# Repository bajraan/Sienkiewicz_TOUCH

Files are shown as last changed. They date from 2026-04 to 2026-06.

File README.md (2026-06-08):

<p align="center" width="100%">
  
</p>

# Sienkiewicz PCB

Sienkiewicz PCB project realized in KiCAD 9

> 🔗 Project main system repository: https://github.com/bajraan/Sienkiewicz__3ART00__SYSTEM

<h1 align="center">3ART12 TOUCH</h1>

<p align="center" width="100%">
  <a href="https://github.com/nguyen-v/KDT_Hierarchical_KiBot/actions/workflows/ci.yaml">
    
  </a>
</p>

***

<p align="center">
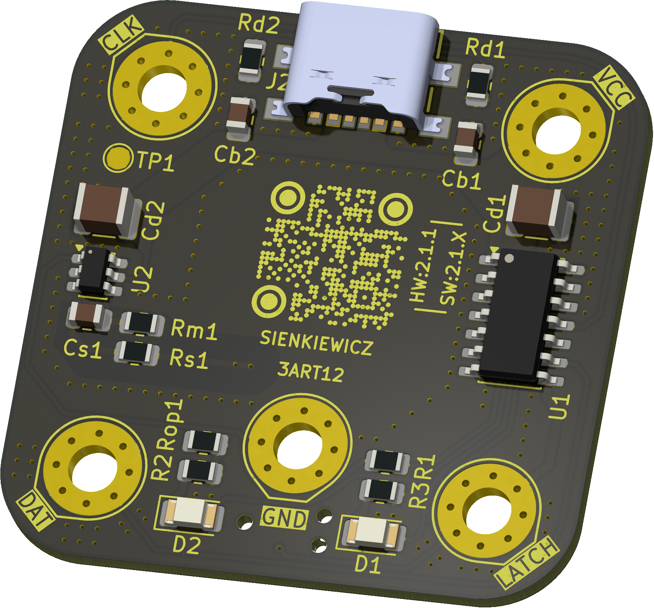
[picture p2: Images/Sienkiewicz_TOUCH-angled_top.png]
3D Top Angled
  
&nbsp; &nbsp; &nbsp; &nbsp;
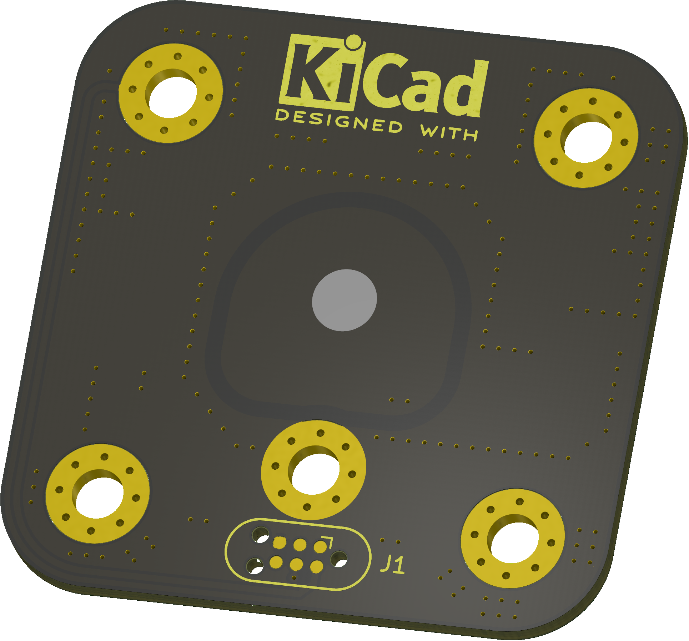
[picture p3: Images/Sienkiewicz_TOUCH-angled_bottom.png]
3D Bottom Angled
  
</p>

***

## SPECIFICATIONS

| Parameter | Value | 
| --- | --- |
| Dimensions | 38.0 × 38.0 mm |

***

## DIRECTORY STRUCTURE

    .
    ├─ Computations       # Misc calculations
    ├─ HTML               # HTML files for generated webpage
    ├─ Images             # Pictures and renders
    │
    ├─ kibot_resources    # External resources for KiBot
    │  ├─ colors          # Color theme for KiCad
    │  ├─ fonts           # Fonts used in the project
    │  ├─ scripts         # External scripts used with KiBot
    │  └─ templates       # Templates for KiBot generated reports
    │
    ├─ kibot_yaml         # KiBot YAML config files
    ├─ KiRI               # KiRI (PCB diff viewer) files
    │
    ├─ lib                # KiCad footprint and symbol libraries
    │  ├─ 3d_models       # Component 3D models
    │  ├─ lib_fp          # Footprint libraries
    │  └─ lib_sym         # Symbol libraries
    │
    ├─ Logos              # Logos
    │
    ├─ Manufacturing      # Assembly and fabrication documents
    │  ├─ Assembly        # Assembly documents (BoM, pos, notes)
    │  │
    │  └─ Fabrication     # Fabrication documents (ZIP, notes)
    │     ├─ Drill Tables # CSV drill tables
    │     └─ Gerbers      # Gerbers
    │
    ├─ Report             # Reports for ERC/DRC
    ├─ Schematic          # PDF of schematic
    ├─ Templates          # Title block templates
    ├─ Testing
    │  └─ Testpoints      # Testpoints tables      
    │
    └─ Variants           # Outputs for assembly variants

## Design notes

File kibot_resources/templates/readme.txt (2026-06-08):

<p align="center" width="100%">
  
</p>

# Sienkiewicz PCB

Sienkiewicz PCB project realized in KiCAD 9

> 🔗 Project main system repository: https://github.com/bajraan/Sienkiewicz__3ART00__SYSTEM

<h1 align="center">${BOARD_NAME}</h1>

<p align="center" width="100%">
  <a href="${GIT_URL}/actions/workflows/ci.yaml">
    CI Badge
  </a>
</p>

***

<p align="center">
  3D Top Angled
&nbsp; &nbsp; &nbsp; &nbsp;
  3D Bottom Angled
</p>

***

## SPECIFICATIONS

| Parameter | Value | 
| --- | --- |
| Dimensions | ${bb_w_mm} × ${bb_h_mm} mm |

***

## DIRECTORY STRUCTURE

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

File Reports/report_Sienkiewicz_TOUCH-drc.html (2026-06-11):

Logo

(https://github.com/INTI-CMNB/KiBot/) | DRC report for Sienkiewicz_TOUCH
| PCB: Sienkiewicz_TOUCH Revision: 2.1.1+ (Unreleased) Date: 2026-06-11T17:48:40+0000 KiCad Version: 9.0.7 | Errors: 0 Warnings: 3 Total: 3

Violations

Type | Description | Details
lib_footprint_mismatch | Footprint 'SOIC-14_3.9x8.7mm_P1.27mm' does not match copy in library 'Package_SO'. | @(161.5 mm, 90.0 mm): Footprint U1
lib_footprint_mismatch | Footprint 'SOT-23-6' does not match copy in library 'Package_TO_SOT_SMD'. | @(133.5 mm, 90.0 mm): Footprint U2

Schematic parity

Type | Description | Details
extra_footprint | Extra footprint | @(148.5 mm, 75.0 mm): Footprint REF**

Generated by KiBot (https://github.com/INTI-CMNB/KiBot/) v1.9.1

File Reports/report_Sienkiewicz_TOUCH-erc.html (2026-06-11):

Logo

(https://github.com/INTI-CMNB/KiBot/) | ERC report for Sienkiewicz_TOUCH
| Schematic: Sienkiewicz_TOUCH Revision: 2.1.1+ (Unreleased) Date: 2026-06-11T17:48:38+0000 KiCad Version: 9.0.7 | Errors: 0 Warnings: 1 Total: 1

Sheet /Project Architecture/Section B - uC/ (Section B - uC.kicad_sch)

Type | Description | Details
pin_to_pin | Pins of type Bidirectional and Power output are connected | @(1.7907 mm, 0.7747 mm): Symbol J1 Pin 2 [SWDIO, Bidirectional, Line] @(1.2954 mm, 0.762 mm): Symbol #FLG01 Pin 1 [Power output, Line]

Generated by KiBot (https://github.com/INTI-CMNB/KiBot/) v1.9.1

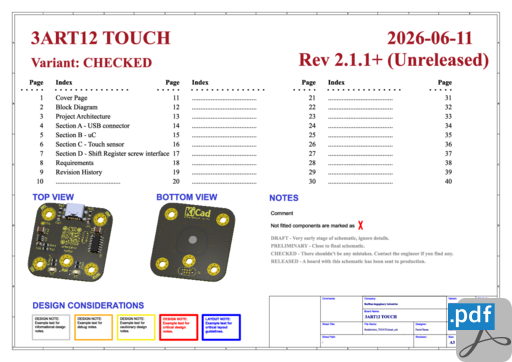
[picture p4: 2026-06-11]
HTML/images/cat_pdf_schematic_Sienkiewicz_TOUCH-schematic.png

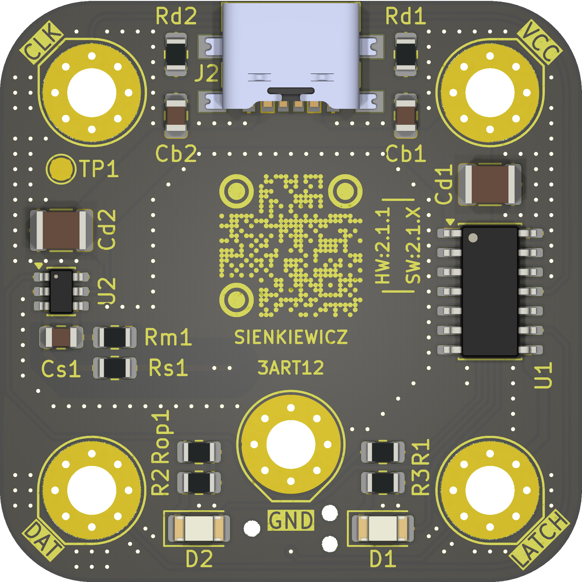
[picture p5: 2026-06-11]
Images/Sienkiewicz_TOUCH-top.png

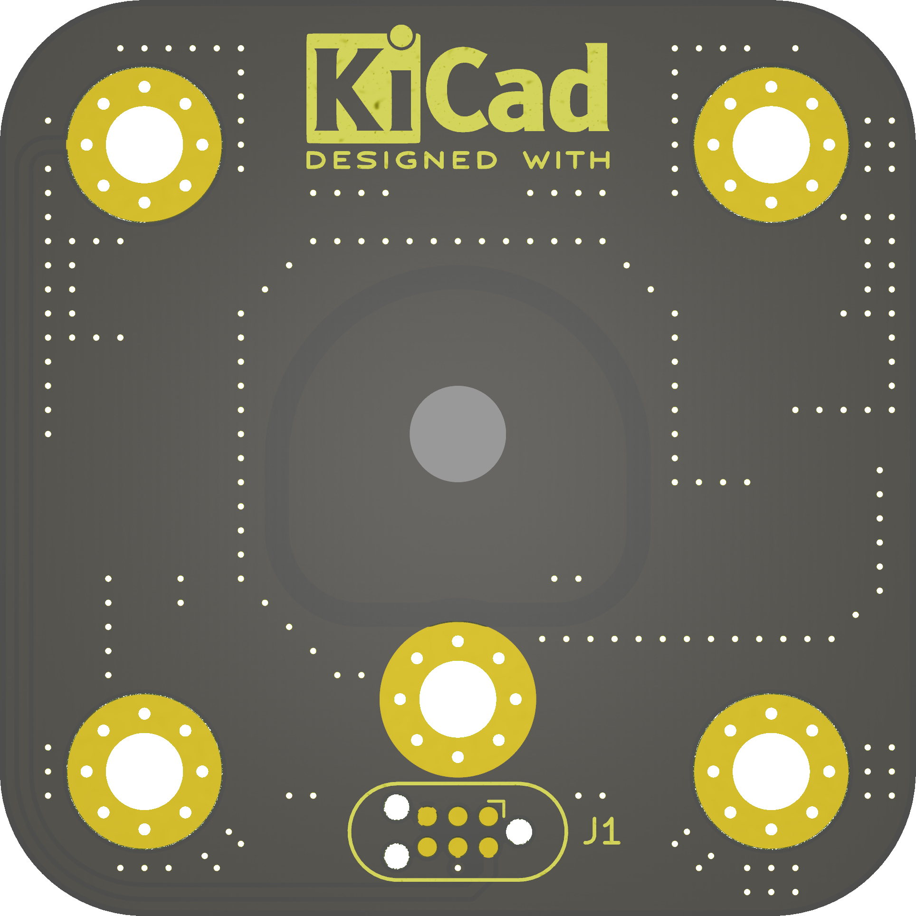
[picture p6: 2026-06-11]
Images/Sienkiewicz_TOUCH-bottom.png

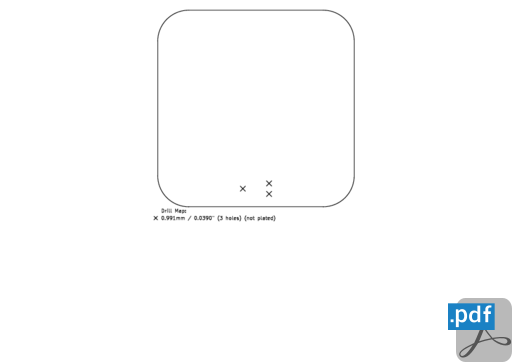
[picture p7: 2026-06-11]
HTML/images/cat_pdf_drill_map_Sienkiewicz_TOUCH-NPTH_drill_map.png

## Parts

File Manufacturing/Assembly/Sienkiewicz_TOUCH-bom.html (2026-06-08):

 | Bill of Materials
 | Schematic: Sienkiewicz_TOUCH Variant: CHECKED Revision: 2.1.1+ (Unreleased) Date: 2025-01-12 KiCad Version: 9.0.7+1 | Component Groups: 13 Component Count: 20 (per PCB) Fitted Components: 20 (per PCB) Number of PCBs: 1 Total Components: 20 (for 1 PCBs)
Row | Quantity Per PCB | References | Value | Datasheet | Footprint | Description | Manufacturer | Manufacturer Part Number | Supplier Part Number
1 | 1 | B1 | BOARD_OUTLINE |  | Sienkiewicz
2 | 2 | Cb1 Cb2 | 1u/16V | ~ | C_0805_2012Metric | Unpolarized capacitor
3 | 2 | Cd1 Cd2 | 100nF | ~ | C_1210_3225Metric | Unpolarized capacitor, small symbol
4 | 1 | Cs1 | 2n7 | ~ | C_0805_2012Metric | Unpolarized capacitor, small symbol
5 | 2 | D1 D2 | RED | ~ | LED_1206_3216Metric | Diode, small symbol
6 | 1 | J2 | USB4135-GF-A_REVA |  | GCT_USB4135-GF-A_REVA |  | GCT
7 | 3 | R1 R2 R3 | 1k | ~ | R_0805_2012Metric | Resistor, small symbol
8 | 3 | Rd1 Rd2 Rs1 | 5k1 | ~ | R_0805_2012Metric | Resistor, small symbol
9 | 1 | Rm1 | 1M | ~ | R_0805_2012Metric | Resistor, small symbol
10 | 1 | Rop1 | 100k | ~ | R_0805_2012Metric | Resistor, small symbol
11 | 1 | TouP1 | TouchPad | ~ | TouchPAD | touch pad
12 | 1 | U2 | AT42QT1012-T | http://ww1.microchip.com/downloads/en/DeviceDoc/40001948A.pdf | SOT-23-6 | Single-Key Touch Sensor IC, SOT-23-6
13 | 1 | U1 | ATtiny204-SS | http://ww1.microchip.com/downloads/en/DeviceDoc/50002687A.pdf | SOIC-14_3.9x8.7mm_P1.27mm | 20MHz, 2kB Flash, 128B SRAM, 64B EEPROM, SOIC-14
Color reference for columns:
KiCad Fields (default)
Generated Fields
User Fields
Empty Fields

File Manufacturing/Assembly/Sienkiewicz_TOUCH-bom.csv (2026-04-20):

Row | Quantity Per PCB | References | Value | Datasheet | Footprint | Description | Manufacturer | Manufacturer Part Number | Supplier Part Number | BOM_STATUS | BOM_INFO
1 | 1 | B1 | BOARD_OUTLINE |  | Sienkiewicz |  |  |  |  | N/A | N/A
2 | 2 | Cb1 Cb2 | 1u/16V | ~ | C_0805_2012Metric | Unpolarized capacitor |  |  |  | OK | TME BOX
3 | 2 | Cd1 Cd2 | 100nF | ~ | C_1210_3225Metric | Unpolarized capacitor, small symbol |  |  |  | OK | AIDATEK A0
4 | 1 | Cs1 | 2n7 | ~ | C_0805_2012Metric | Unpolarized capacitor, small symbol |  |  |  | OK | TME BOX
5 | 2 | D1 D2 | RED | ~ | LED_1206_3216Metric | Diode, small symbol |  |  |  | OK | AIDATEK A0
6 | 1 | J2 | USB4135-GF-A_REVA |  | GCT_USB4135-GF-A_REVA |  | GCT |  |  | OK | TME BOX
7 | 3 | R1 R2 R3 | 1k | ~ | R_0805_2012Metric | Resistor, small symbol |  |  |  | OK | AIDATEK A0
8 | 3 | Rd1 Rd2 Rs1 | 5k1 | ~ | R_0805_2012Metric | Resistor, small symbol |  |  |  | OK | TME BOX 25.06.2025
9 | 1 | Rm1 | 1M | ~ | R_0805_2012Metric | Resistor, small symbol |  |  |  | OK | TME BOX
10 | 1 | Rop1 | 100k | ~ | R_0805_2012Metric | Resistor, small symbol |  |  |  | OK | TME BOX
11 | 1 | TouP1 | TouchPad | ~ | TouchPAD | touch pad |  |  |  | N/A | N/A
12 | 1 | U2 | AT42QT1012-T | http://ww1.microchip.com/downloads/en/DeviceDoc/40001948A.pdf | SOT-23-6 | Single-Key Touch Sensor IC, SOT-23-6 |  |  |  | OK | TME BOX
13 | 1 | U1 | ATtiny204-SS | http://ww1.microchip.com/downloads/en/DeviceDoc/50002687A.pdf | SOIC-14_3.9x8.7mm_P1.27mm | 20MHz, 2kB Flash, 128B SRAM, 64B EEPROM, SOIC-14 |  |  |  | OK | AIDATEK A1

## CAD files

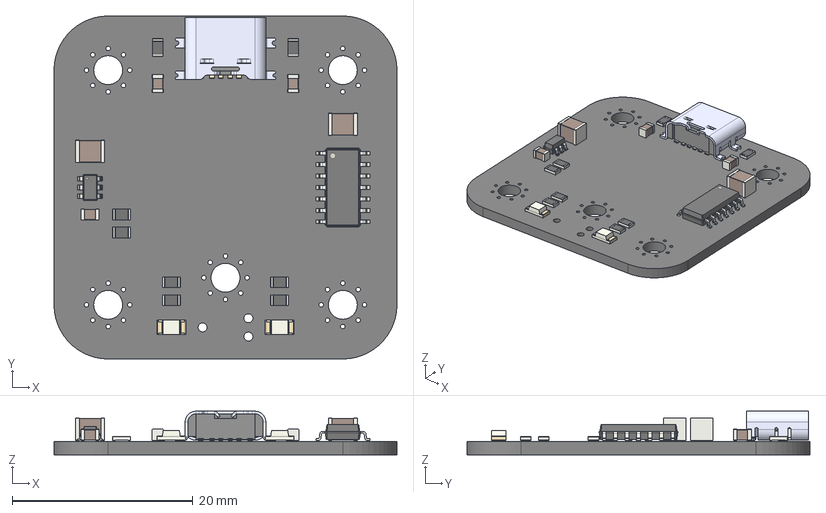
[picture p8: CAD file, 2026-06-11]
3D/Sienkiewicz_TOUCH.step
38.0 x 38.0 x 4.84 mm
R_0805_2012Metric x 8
LED_1206_3216Metric x 2
SOIC-14_3.9x8.7mm_P1.27mm
C_0805_2012Metric x 3
C_1210_3225Metric x 2
USB4135-GF-A_REVA
SOT-23-6
kibot_naao430z_PCB

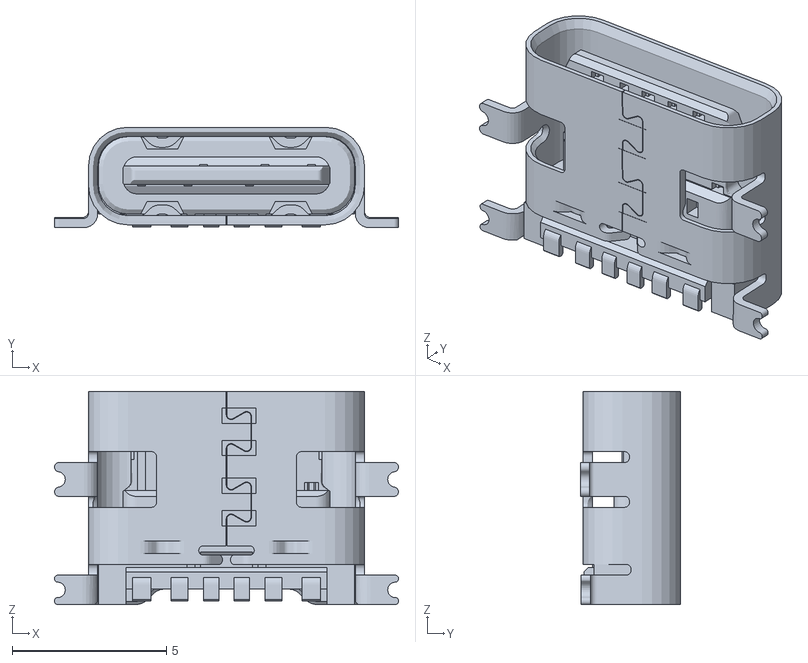
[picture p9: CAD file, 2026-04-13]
__GCT_USB4135-GF-A/usb4135-gf-a.stl
11.1 x 3.25 x 6.90

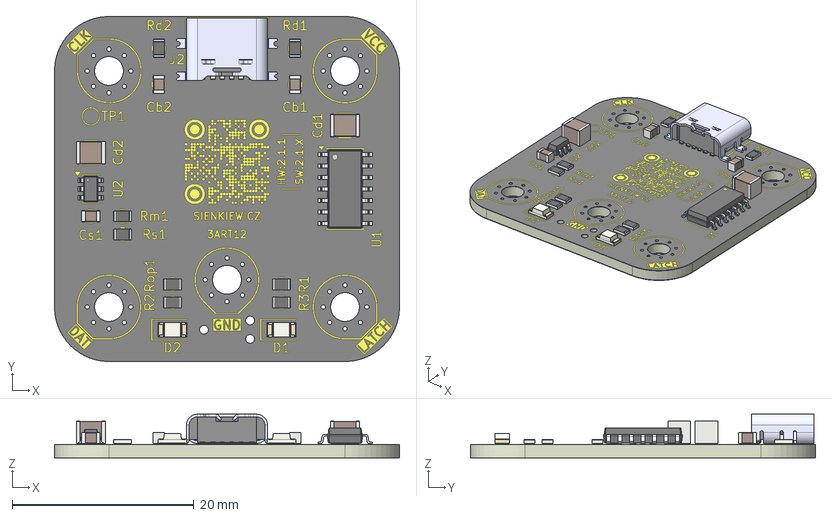
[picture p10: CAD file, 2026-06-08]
STEP_Blender/KDT_Hierarchical_KiBot.step
38.0 x 38.0 x 4.91 mm
R_0805_2012Metric x 8
LED_1206_3216Metric x 2
SOIC-14_3.9x8.7mm_P1.27mm
C_0805_2012Metric x 3
C_1210_3225Metric x 2
USB4135-GF-A_REVA
SOT-23-6
Sienkiewicz_TOUCH_silkscreen x 2
Sienkiewicz_TOUCH_soldermask x 2
Sienkiewicz_TOUCH_PCB

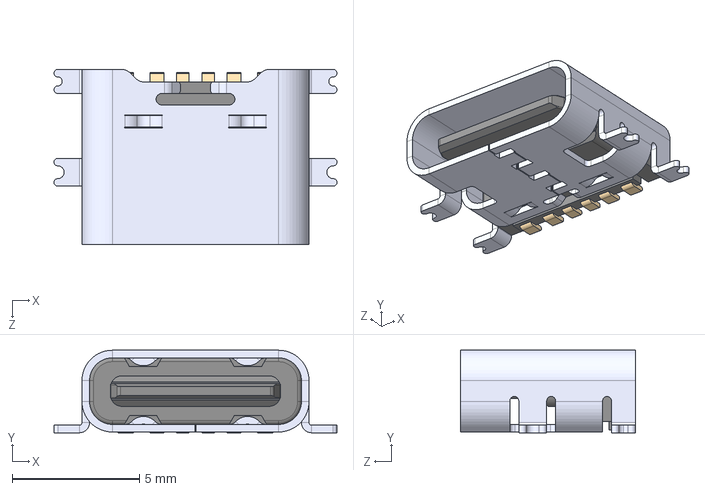
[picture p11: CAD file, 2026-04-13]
__GCT_USB4135-GF-A/USB4135-GF-A_REVA.step
11.1 x 3.25 x 6.90 mm

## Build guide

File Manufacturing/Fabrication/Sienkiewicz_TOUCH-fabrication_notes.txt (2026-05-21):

FABRICATION NOTES (UNLESS OTHERWISE SPECIFIED)

1)	FABRICATE PER IPC-6012A CLASS 2.

2)	OUTLINE DEFINED IN SEPARATE GERBER FILE WITH
	"Edge_Cuts.GBR" SUFFIX.

	DIMENSIONS OF CIRCUMSIZED RECTANGLE SHOWN ON THIS
	DRAWING FOR REFERENCE ONLY.

3)	SEE SEPARATE DRILL FILES WITH ".DRL" SUFFIX 
	FOR HOLE LOCATIONS.

	SELECTED HOLE LOCATIONS SHOWN ON THIS DRAWING 
	FOR REFERENCE ONLY.

4)	SURFACE FINISH: IMMERSION GOLD

5)	SOLDERMASK ON BOTH SIDES OF THE BOARD SHALL 
	BE LPI, COLOR BLACK.

6)	SILK SCREEN LEGEND TO BE APPLIED PER LAYER 
	STACKUP USING YELLOW NON-CONDUCTIVE EPOXY INK.

7)	ALL VIAS ARE TENTED ON BOTH SIDES UNLESS 
	SOLDERMASK OPENED IN GERBER.

8)	VENDOR SHOULD FOLLOW ROHS COMPLIANT PROCESS 
	AND Pb FREE FOR MANUFACTURING

9)	PCB MATERIAL REQUIREMENTS:

	A.	FLAMMABILITY RATING MUST MEET OR EXCEED 
		UL94V-0 REQUIREMENTS.
	B.	Tg 170 C OR EQUIVALENT.
	C.	EQUIVALENT MATERIAL SHALL BE RoHS COMPLIANT, 
		HALOGEN FREE AND APPROVED BY BAJRAN IMGAGINARY INDUSTRIES.

10)	DESIGN GEOMETRY MINIMUM FEATURE SIZES:

	BOARD SIZE				38.000 × 38.000 mm
	BOARD THICKNESS		1.610 mm
	TRACE WIDTH			0.200 mm
	TRACE TO TRACE		-0.000 mm
	MIN. HOLE (PTH)			0.250 mm
	MIN. HOLE (NPTH)		1.000 mm
	ANNULAR RING			0.150 mm
	COPPER TO HOLE		0.254 mm
	COPPER TO EDGE		0.250 mm
	HOLE TO HOLE			0.254 mm

11)	REFER TO IMPEDANCE TABLE FOR IMPEDANCE CONTROL REQUIREMENTS.

12)	CONFIRM SPACE WIDTHS AND SPACINGS.

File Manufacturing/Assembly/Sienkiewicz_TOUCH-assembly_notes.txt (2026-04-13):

ASSEMBLY NOTES (UNLESS OTHERWISE SPECIFIED)

1)	DO NOT POPULATE PARTS ARE MARKED WITH A RED CROSS.

2)	DO NOT POPULATE PARTS ARE NOT PRESENT IN THE BOM.

3)	IF CONFLICTING INFORMATION IS FOUND BETWEEN THE ASSEMBLY
	FILE AND BOM, BOM SHOULD BE USED AS THE MAIN SOURCE.

4)	CONFORMAL COATING IS NOT REQUIRED.

5)	DOT IDENTIFIES PIN #1 LOCATION AND DEVICE ORIENTATION
	WHEN VIEWED FROM THE TOP.

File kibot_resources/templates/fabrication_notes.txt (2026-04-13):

FABRICATION NOTES (UNLESS OTHERWISE SPECIFIED)

1)	FABRICATE PER IPC-6012A CLASS 2.

2)	OUTLINE DEFINED IN SEPARATE GERBER FILE WITH
	"Edge_Cuts.GBR" SUFFIX.

	DIMENSIONS OF CIRCUMSIZED RECTANGLE SHOWN ON THIS
	DRAWING FOR REFERENCE ONLY.

3)	SEE SEPARATE DRILL FILES WITH ".DRL" SUFFIX 
	FOR HOLE LOCATIONS.

	SELECTED HOLE LOCATIONS SHOWN ON THIS DRAWING 
	FOR REFERENCE ONLY.

4)	SURFACE FINISH: ${pcb_finish_cap}

5)	SOLDERMASK ON BOTH SIDES OF THE BOARD SHALL 
	BE LPI, COLOR ${solder_mask_color_text_cap}.

6)	SILK SCREEN LEGEND TO BE APPLIED PER LAYER 
	STACKUP USING ${silk_screen_color_text_cap} NON-CONDUCTIVE EPOXY INK.

7)	ALL VIAS ARE TENTED ON BOTH SIDES UNLESS 
	SOLDERMASK OPENED IN GERBER.

8)	VENDOR SHOULD FOLLOW ROHS COMPLIANT PROCESS 
	AND Pb FREE FOR MANUFACTURING

9)	PCB MATERIAL REQUIREMENTS:

	A.	FLAMMABILITY RATING MUST MEET OR EXCEED 
		UL94V-0 REQUIREMENTS.
	B.	Tg 170 C OR EQUIVALENT.
	C.	EQUIVALENT MATERIAL SHALL BE RoHS COMPLIANT, 
		HALOGEN FREE AND APPROVED BY ${COMPANY_cap}.

10)	DESIGN GEOMETRY MINIMUM FEATURE SIZES:

	BOARD SIZE				${bb_w_mm} × ${bb_h_mm} mm
	BOARD THICKNESS		${thickness_mm} mm
	TRACE WIDTH			${track_mm} mm
	TRACE TO TRACE		${clearance_mm} mm
	MIN. HOLE (PTH)			${drill_pth_real_mm} mm
	MIN. HOLE (NPTH)		${drill_npth_real_mm} mm
	ANNULAR RING			${oar_mm} mm
	COPPER TO HOLE		${c2h_mm} mm
	COPPER TO EDGE		${c2e_mm} mm
	HOLE TO HOLE			${h2h_mm} mm
#?stackup and impedance_controlled

#?stackup and impedance_controlled
11)	REFER TO IMPEDANCE TABLE FOR IMPEDANCE CONTROL REQUIREMENTS.
#?stackup and impedance_controlled

#?stackup and impedance_controlled
12)	CONFIRM SPACE WIDTHS AND SPACINGS.

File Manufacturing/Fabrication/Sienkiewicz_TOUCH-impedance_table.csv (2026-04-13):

Transmission Line | Impedance [ohms] | Tolerance [ohms] | Layer | Trace Width [mm] | Gap [mm] | Ref. Layers
Edge-Coupled Coated Microstrip | 100 | ±10 % | L1 | 0.2032 | 0.28 | L2

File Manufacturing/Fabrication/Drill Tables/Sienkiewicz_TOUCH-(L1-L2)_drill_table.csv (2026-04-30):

Count | Hole Size | Plated | Hole Shape | Drill Layer Pair | Hole Type
183 | 0.25mm (9.84mils) | PTH | Round | F.Cu - B.Cu | Via
40 | 0.50mm (19.69mils) | PTH | Round | F.Cu - B.Cu | Pad
5 | 3.20mm (125.98mils) | PTH | Round | F.Cu - B.Cu | Pad
Total 228

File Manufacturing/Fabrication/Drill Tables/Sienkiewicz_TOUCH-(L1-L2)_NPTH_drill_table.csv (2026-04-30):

Count | Hole Size | Plated | Hole Shape | Drill Layer Pair | Hole Type
3 | 0.99mm (39.00mils) | NPTH | Round | F.Cu - B.Cu | Mechanical
Total 3

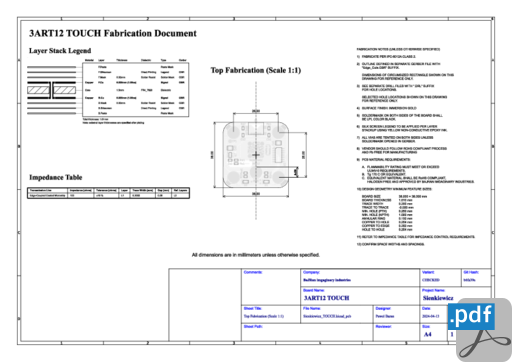
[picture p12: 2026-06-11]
HTML/images/cat_pdf_fabrication_Sienkiewicz_TOUCH-fabrication.png

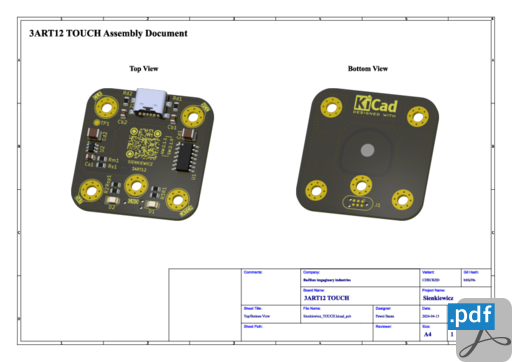
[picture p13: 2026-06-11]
HTML/images/cat_pdf_assembly_Sienkiewicz_TOUCH-assembly.png

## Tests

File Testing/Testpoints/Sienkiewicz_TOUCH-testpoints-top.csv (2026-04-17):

Ref. | Net | X [mm] | Y [mm]
TP1 | GND | 69.50 | 24.00

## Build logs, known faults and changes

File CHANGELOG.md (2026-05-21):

# Changelog

## [Unreleased]

## [2.1.1] - 2026-05-21

### Changed

-   B-B connector maping changes restored (fixes #4)

### Added

-   requirements section added for documentation

## [2.1.0] - 2026-05-01

### Changed

-   B-B connector maping changes, CLK and SDI swapped (fixes #4)

## [2.0.2] - 2026-04-26

### Changed

-   Modified silkscreen look
-   Fabrication layers update

## [2.0.1] - 2026-04-25

### Changed

-   Modified silkscreen look, by adding bigger QR-code. small rearangment.

## [2.0.0] - 2026-04-24

### Added

-   First 2.0.0 Version of pcb and schematic

[Unreleased]: https://github.com/bajraan/Sienkiewicz_TOUCH/compare/2.1.1...HEAD

[2.1.1]: https://github.com/bajraan/Sienkiewicz_TOUCH/compare/2.1.0...2.1.1

[2.1.0]: https://github.com/bajraan/Sienkiewicz_TOUCH/compare/2.0.2...2.1.0

[2.0.2]: https://github.com/bajraan/Sienkiewicz_TOUCH/compare/2.0.1...2.0.2

[2.0.1]: https://github.com/bajraan/Sienkiewicz_TOUCH/compare/2.0.0...2.0.1

[2.0.0]: https://github.com/bajraan/Sienkiewicz_TOUCH/compare/a58dfeffc68793d9061ed17c15873d52f7ee5985...2.0.0

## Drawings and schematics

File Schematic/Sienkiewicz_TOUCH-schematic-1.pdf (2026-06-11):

# Variant:CHECKED

# 3ART12TOUCH

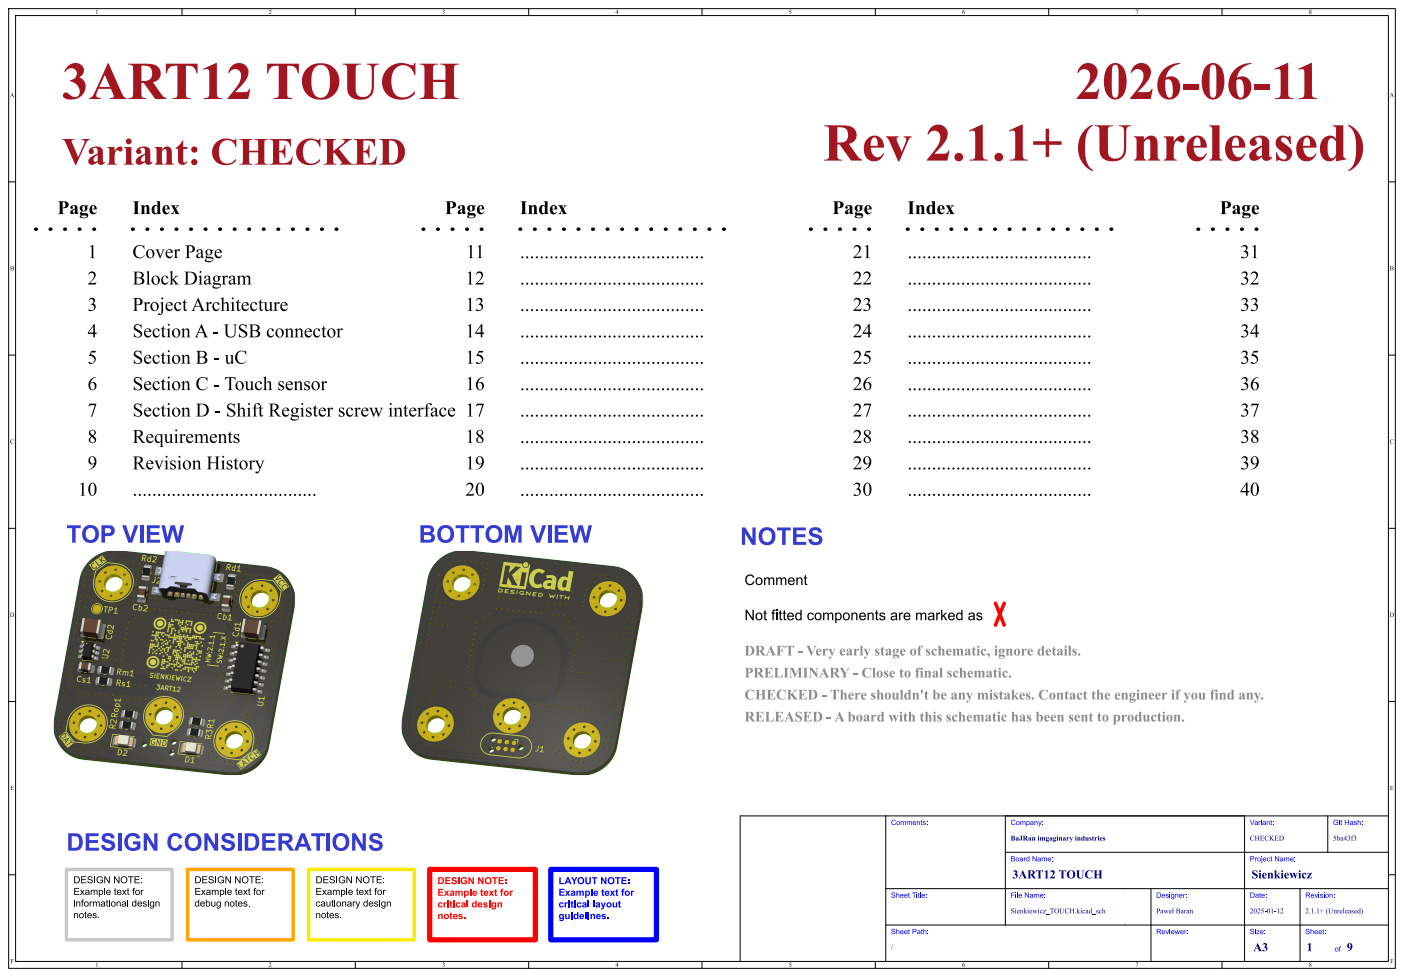
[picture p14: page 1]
Sheet: of 9; Size: A3; Sienkiewicz_TOUCH.kicad_sch; þÿPaweB Baran Board Name:; Variant: CHECKED; Company: BaJRanimgaginaryindustries 3ART12TOUCH; Sienkiewicz; Sheet Title:; File Name:; /Sheet Path: Comments:; Git Hash: 5ba43f3 ProjectArchitecture; kibot_image_png_3d_viewer_angled_bottom; LAYOUT NOTE:; kibot_image_png_3d_viewer_angled_top; DESIGN NOTE:; RELEASED - A boardwiththisschematichasbeensenttoproduction.; RevisionHistory; Index; Page; NOTES; Comment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

CoverPage
Block Diagram
ProjectArchitecture
SectionA - USBconnector
...................................... SectionB - uC
SectionC - Touchsensor
SectionD - Shift Registerscrewinterface
Requirements

Not fitted components are marked as

DRAFT - Veryearlystageof schematic,ignoredetails.
PRELIMINARY - Closetofinal schematic.

Revision: 2.1.1+(Unreleased) Date: Project Name: 2025-01-12 Reviewer: Designer:

DESIGN NOTE:
Example text for
informational design
notes.

debug notes.

critical design

cautionary design

critical layout
guidelines.

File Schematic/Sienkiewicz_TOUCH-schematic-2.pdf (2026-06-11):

## Page5

# STATUS

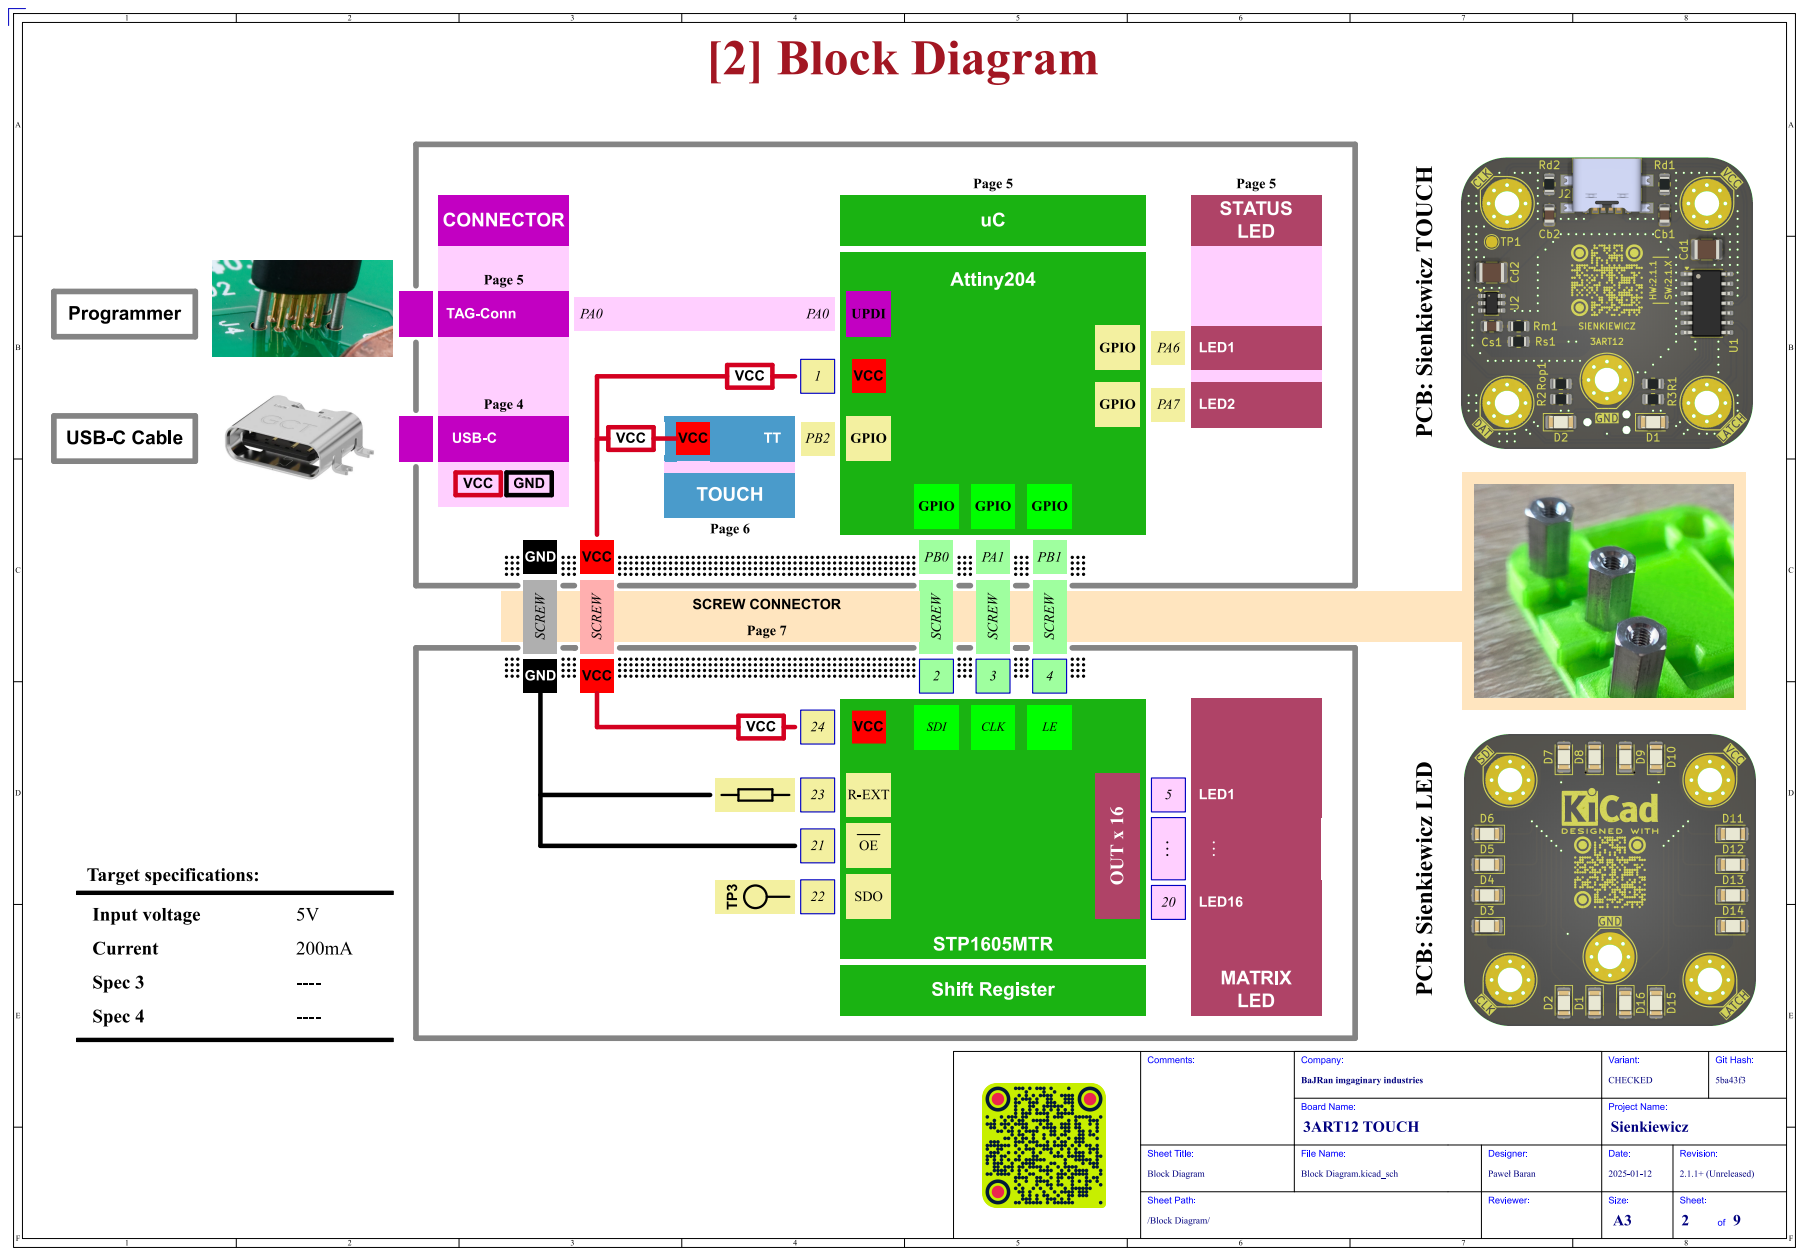
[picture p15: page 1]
Sheet: of 9; Size: A3; Revision: 2.1.1+(Unreleased) Date: Project Name: 2025-01-12 Reviewer: Designer: Block Diagram.kicad_sch; þÿPaweB Baran Board Name:; Variant: CHECKED; Company: BaJRanimgaginaryindustries 3ART12TOUCH; Sienkiewicz; Sheet Title:; File Name:; Comments:; Git Hash: 5ba43f3 5; LED1; VCC; LED; LED2; Page6; GPIO; STP1605MTR; Shift Register; OUT; TOUCH; Spec4; CONNECTOR; USB-C; TAG-Conn; Page5; SCREW; USB-C Cable; Spec3; Current; Input voltage; Targetspecifications:; GND; LED16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

/Block Diagram/ Sheet Path: Block Diagram

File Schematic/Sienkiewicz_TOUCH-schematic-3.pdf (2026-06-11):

## SectionB - uC

# [3] ProjectArchitecture

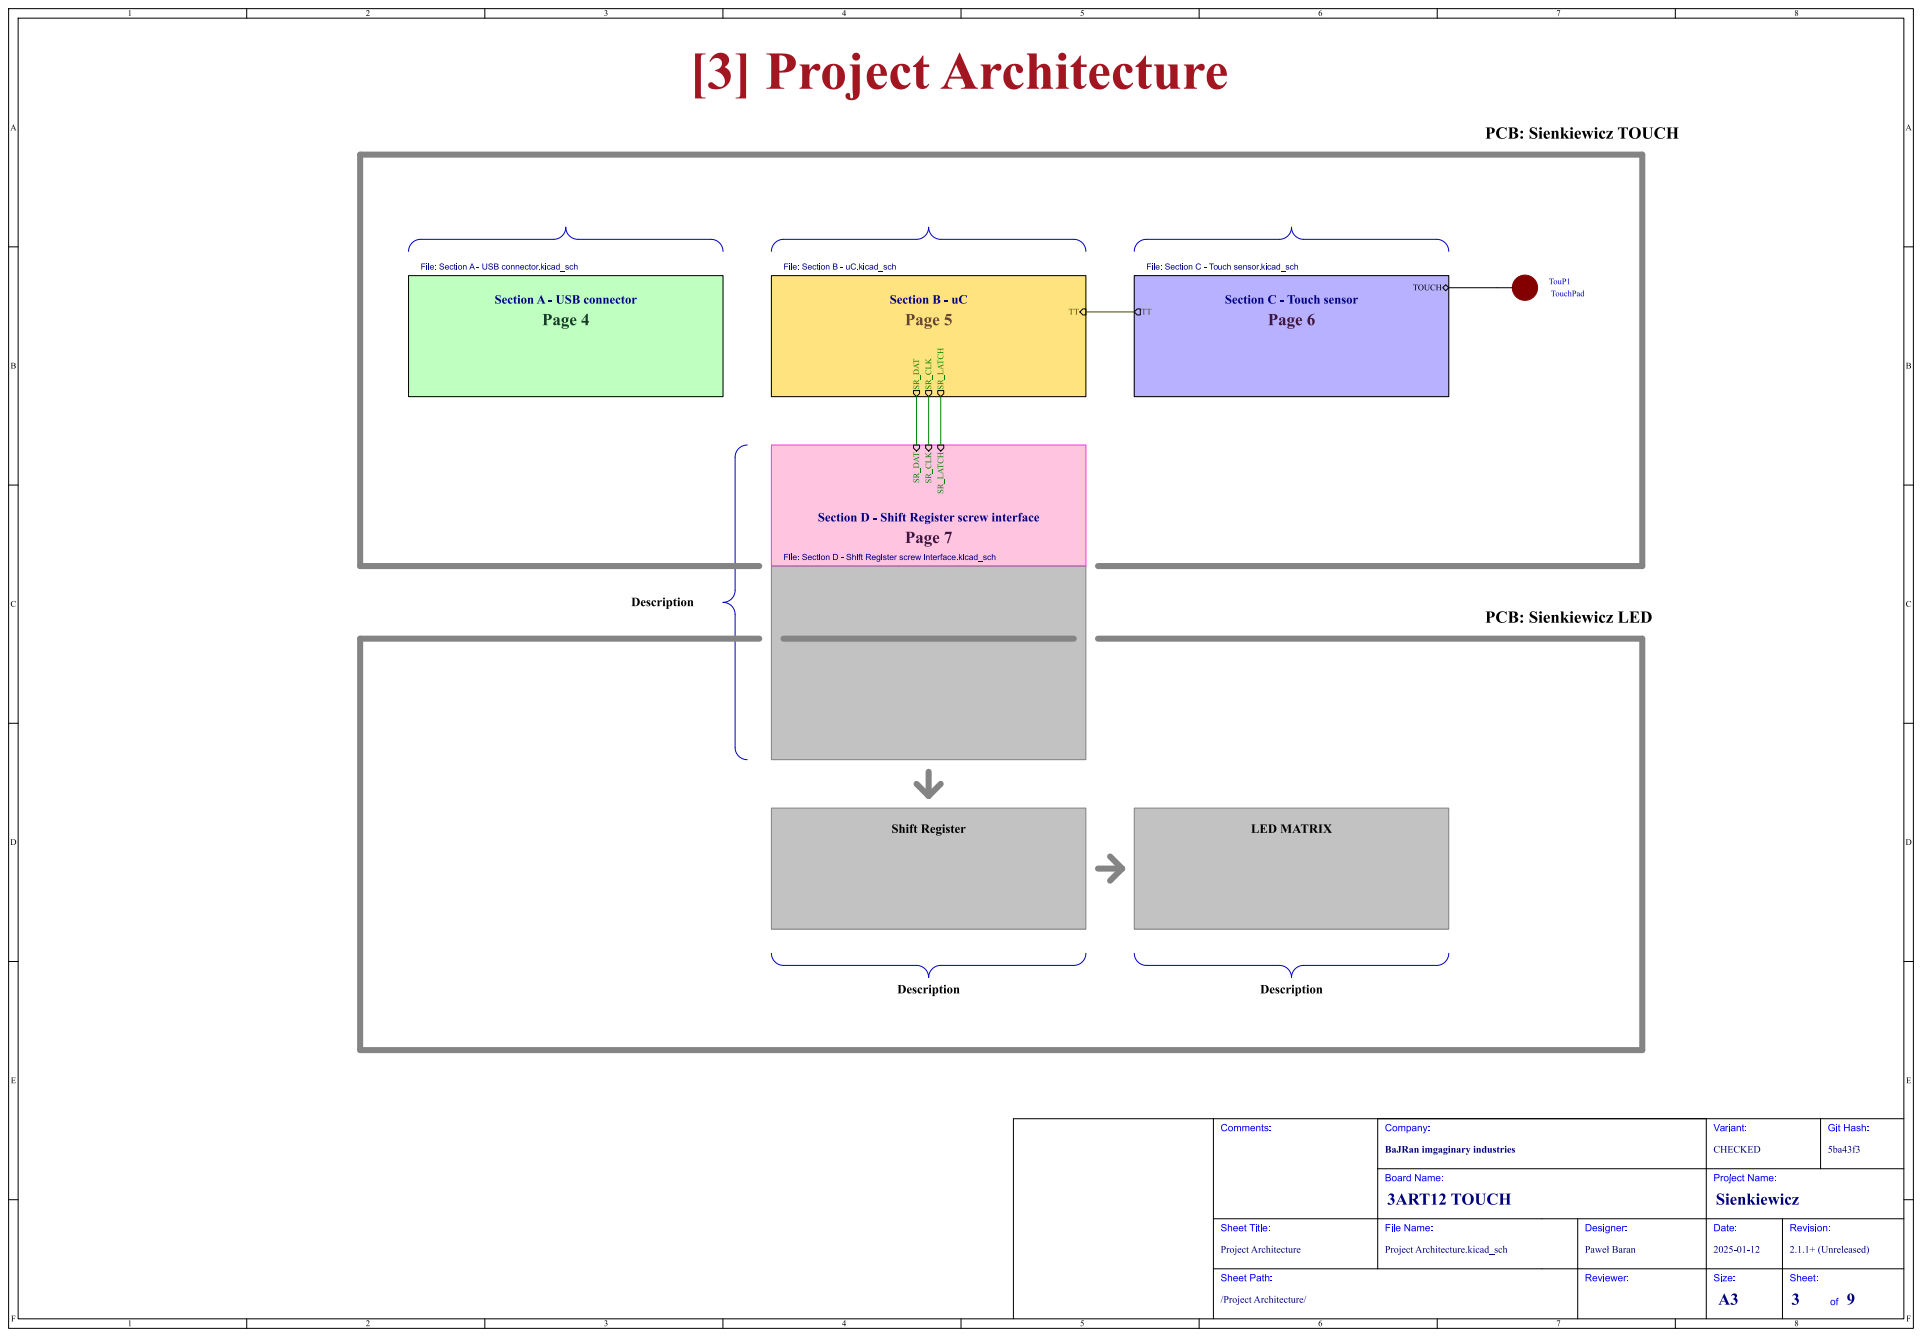
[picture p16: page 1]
Sheet: of 9; Size: A3; ProjectArchitecture.kicad_sch; þÿPaweB Baran Board Name:; Variant: CHECKED; Company: BaJRanimgaginaryindustries 3ART12TOUCH; Sienkiewicz; Sheet Title:; File Name:; /ProjectArchitecture/ Sheet Path: ProjectArchitecture Comments:; Git Hash: 5ba43f3; SectionA - USBconnector File: Section A - USB connector.kicad_sch; TOUCH; SectionC - Touchsensor File: Section C - Touch sensor.kicad_sch TT SR_DAT SR_CLK SR_LATCH; File: Section B - uC.kicad_sch; SR_CLK SR_LATCH SR_DAT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

Revision: 2.1.1+(Unreleased) Date: Project Name: 2025-01-12 Reviewer: Designer:

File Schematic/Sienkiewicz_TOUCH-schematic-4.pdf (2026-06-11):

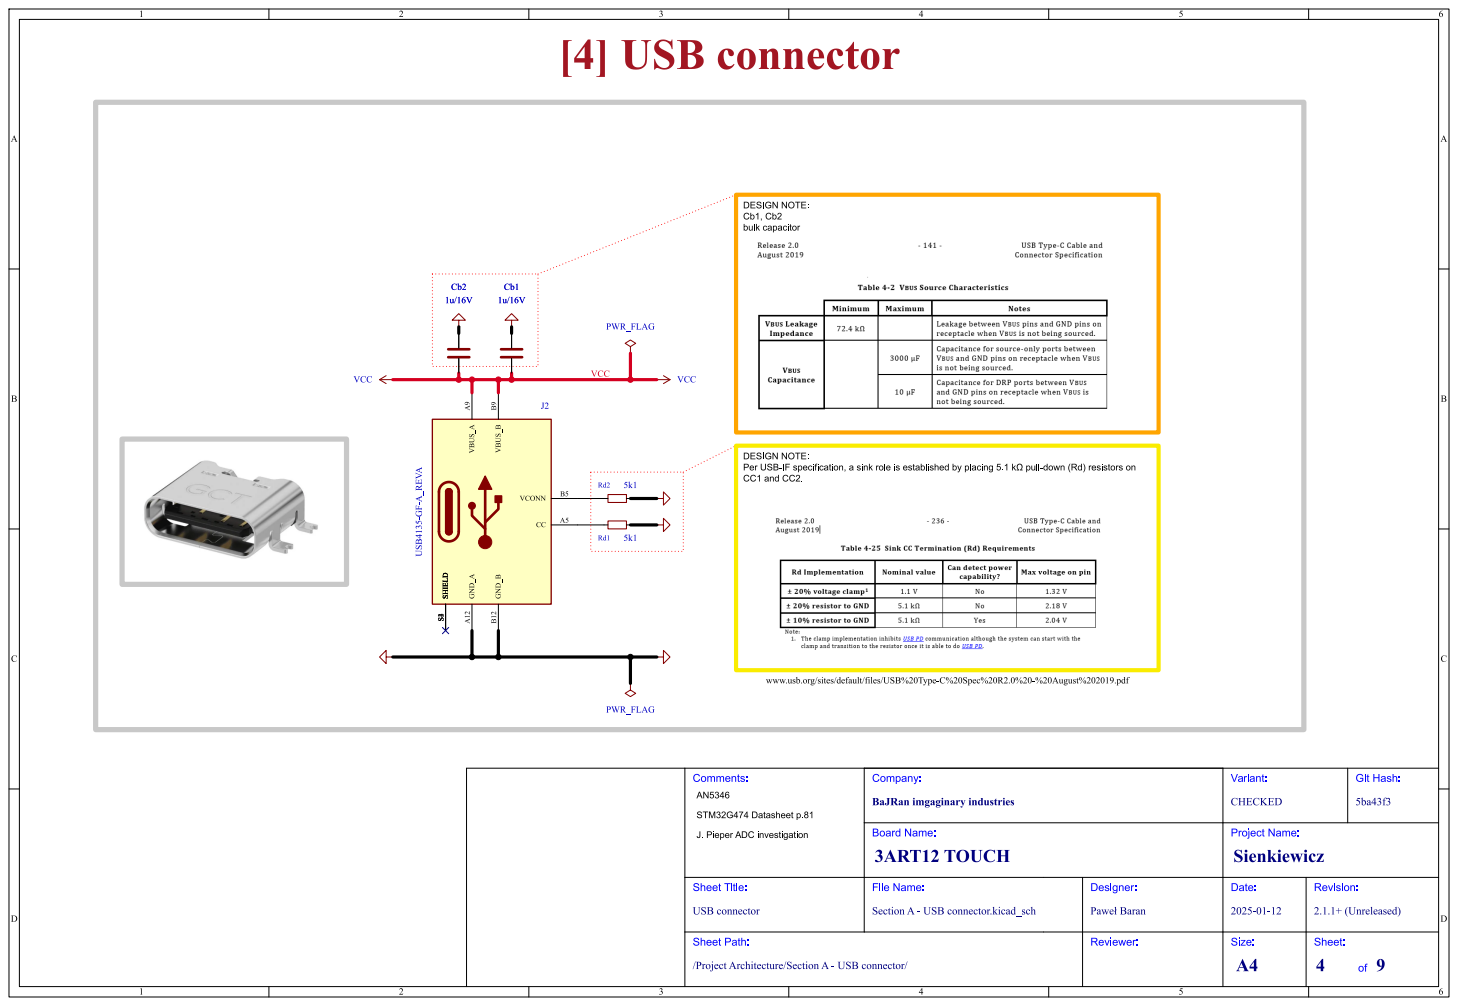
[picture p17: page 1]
Sheet: of 9; Size: A4; Revision: 2.1.1+(Unreleased) Date: Project Name: 2025-01-12 Reviewer: Designer: SectionA - USBconnector.kicad_sch; þÿPaweB Baran Board Name:; Variant: CHECKED; Company: BaJRanimgaginaryindustries 3ART12TOUCH; Sienkiewicz; Sheet Title:; File Name:; /ProjectArchitecture/SectionA - USBconnector/ Sheet Path: USBconnector Comments:; Git Hash: 5ba43f3; VCC; PWR_FLAG; SHIELD S¹²³⁴; VBUS_A A⁹ GND_A A¹²; VBUS_B B⁹ GND_B B¹²; VCONN; A5 J2 USB⁴¹³⁵⁻GF⁻A_REVA; DESIGN NOTE: Cb1, Cb2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

DESIGN NOTE: Per USB-IF specification, a sink role is established by placing 5.1 þÿk©pull-down (Rd) resistors on CC1 and CC2. [4] USBconnector

www.usb.org/sites/default/files/USB%20Type-C%20Spec%20R2.0%20-%20August%202019.pdf STM32G474 Datasheet p.81

J. Pieper ADC investigation (https://jpieper.com/2023/07/24/stm32g4-adc-performance-part-2/) AN5346

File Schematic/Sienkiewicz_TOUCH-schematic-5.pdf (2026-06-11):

# [5] uC & progconnector

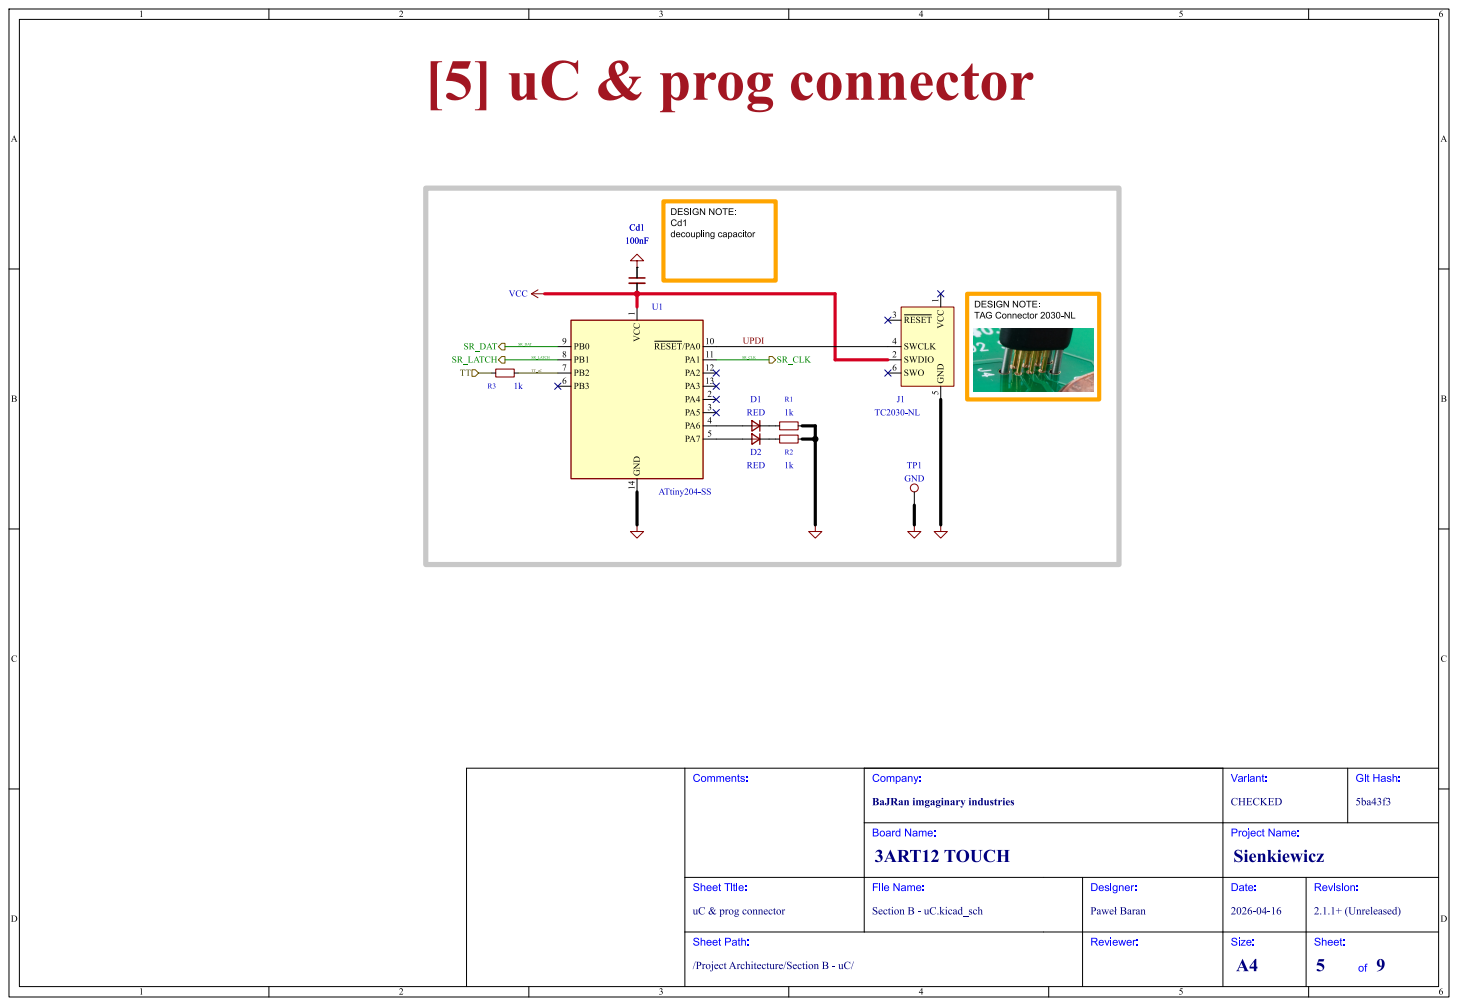
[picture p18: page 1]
Sheet: of 9; Size: A4; Revision: 2.1.1+(Unreleased) Date: Project Name: 2026-04-16 Reviewer: Designer: SectionB - uC.kicad_sch; þÿPaweB Baran Board Name:; Variant: CHECKED; Company: BaJRanimgaginaryindustries 3ART12TOUCH; Sienkiewicz; Sheet Title:; File Name:; /ProjectArchitecture/SectionB - uC/ Sheet Path: uC & progconnector Comments:; Git Hash: 5ba43f3; VCC; 1 GND 14; ~{RESET}/PA010 PA1 11 PA2 12 PA3 13 PA4 2 PA5 3 PA6 4 PA7 5 U1ATtiny204-SS; TP1 GND VCC; 1 GND; D1 RED; R1 1kR2 1k D2 RED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

5 ~{RESET} 3 SWCLK 4 SWDIO 2 SWO 6

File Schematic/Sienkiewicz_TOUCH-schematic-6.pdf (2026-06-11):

# [6] TouchSensor

# ACTIVE HIGH OUTPUT

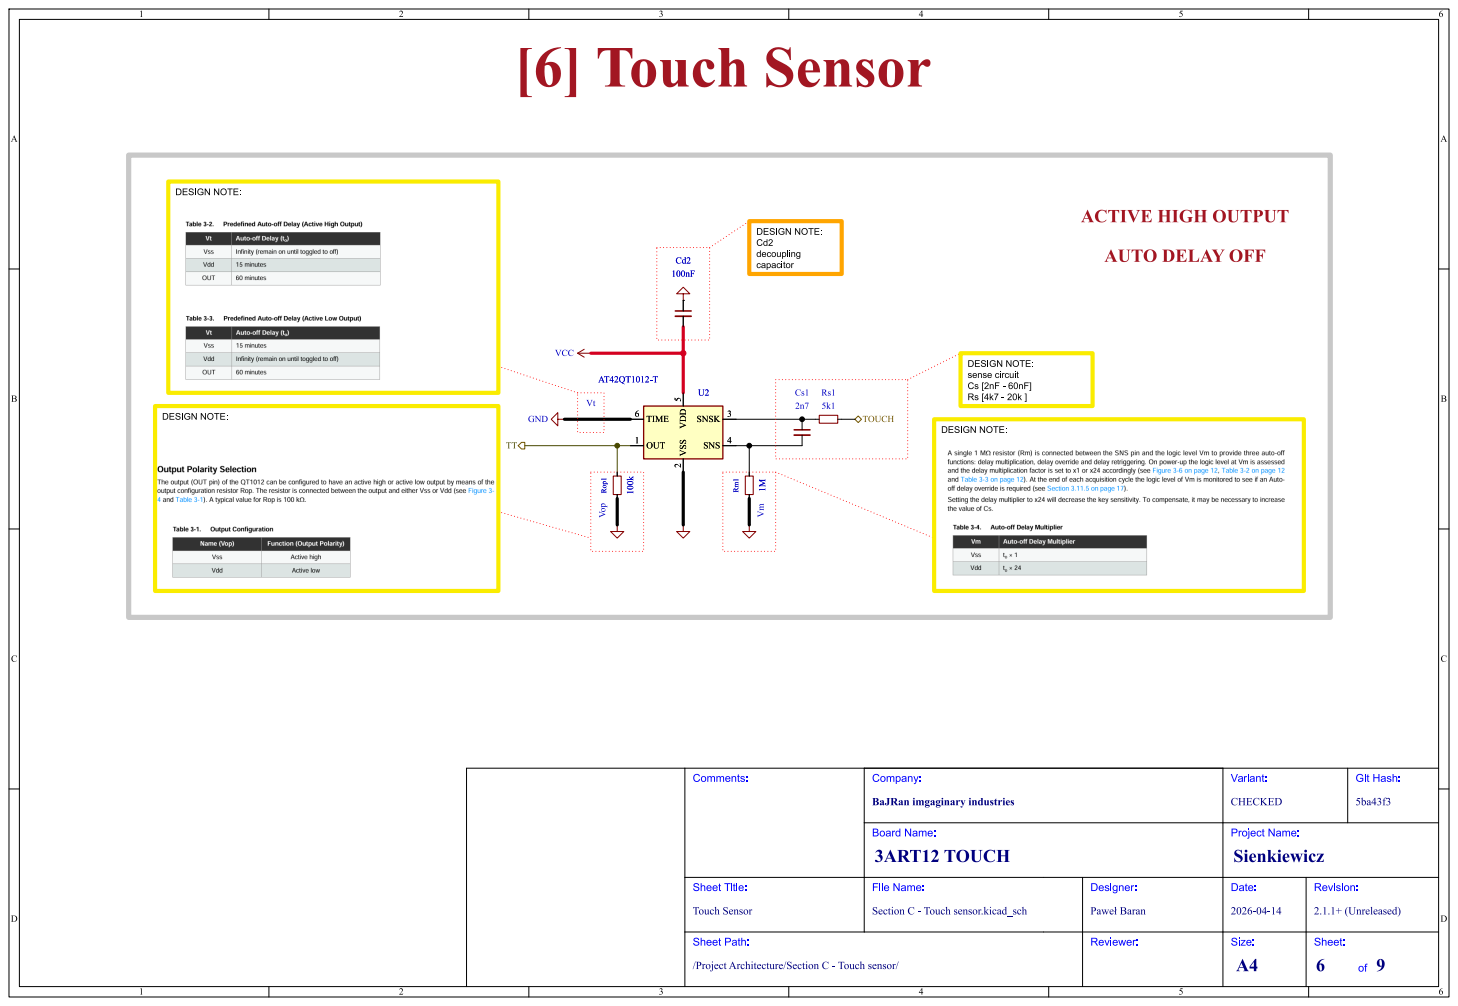
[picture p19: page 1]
Sheet: of 9; Size: A4; Revision: 2.1.1+(Unreleased) Date: Project Name: 2026-04-14 Reviewer: Designer: SectionC - Touchsensor.kicad_sch; þÿPaweB Baran Board Name:; Variant: CHECKED; Company: BaJRanimgaginaryindustries 3ART12TOUCH; Sienkiewicz; Sheet Title:; File Name:; /ProjectArchitecture/SectionC - Touchsensor/ Sheet Path: TouchSensor Comments:; Git Hash: 5ba43f3 Rop1; Rm¹; VCC GND; TIME 6 OUT 1; VDD; 5 VSS; 2 SNSK 3 SNS 4 U2 AT42QT1012-T; TOUCH; DESIGN NOTE: Cd2; decoupling capacitor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

AUTO DELAY OFF

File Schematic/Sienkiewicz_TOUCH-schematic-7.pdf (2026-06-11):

# SR_DAT SR_LATCH [7] ShiftRegisterscrewinterface

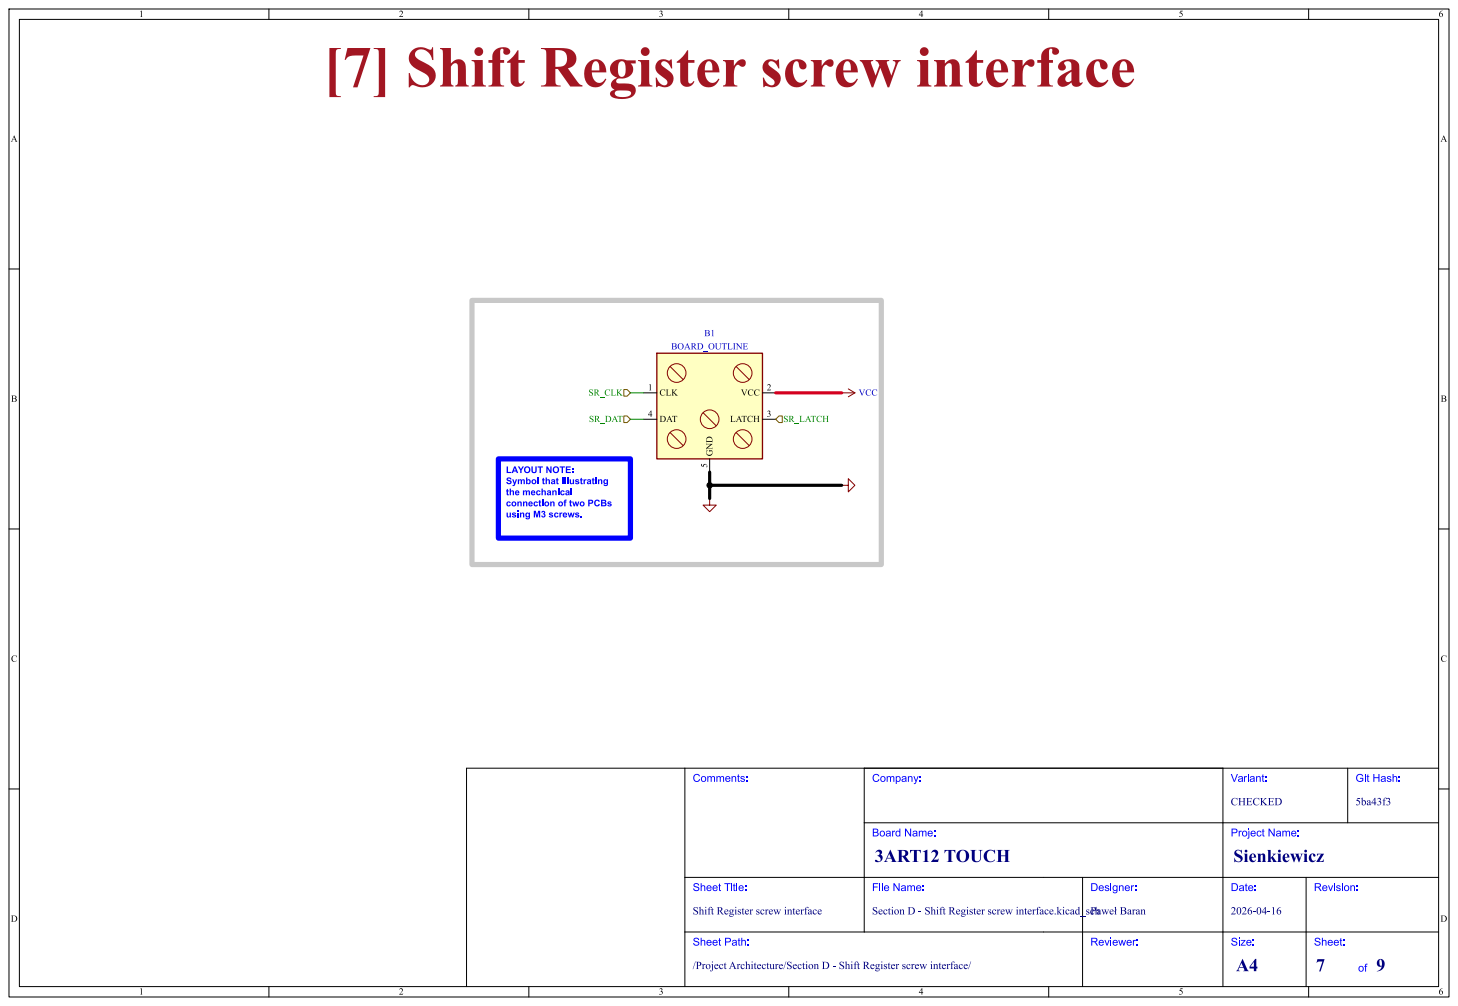
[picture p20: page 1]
Sheet: of 9; Size: A4; Date:; Revision: Project Name: 2026-04-16 Reviewer: Designer: SectionD - Shift Registerscrewinterface.kicad_sch þÿPaweB Baran Board Name:; Variant: CHECKED; Company:; 3ART12TOUCH; Sienkiewicz; Sheet Title:; File Name:; /ProjectArchitecture/SectionD - Shift Registerscrewinterface/ Sheet Path: Shift Registerscrewinterface Comments:; Git Hash: 5ba43f3 CLK; VCC 1 DAT 4; GND; 5 VCC 2; LATCH 3 B1 BOARD_OUTLINE; SR_CLK

LAYOUT NOTE: Symbol that illustrating

the mechanical connection of two PCBs using M3 screws.

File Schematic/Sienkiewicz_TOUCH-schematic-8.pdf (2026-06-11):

# [8] Requirements

## MAIN OBJECTIVE

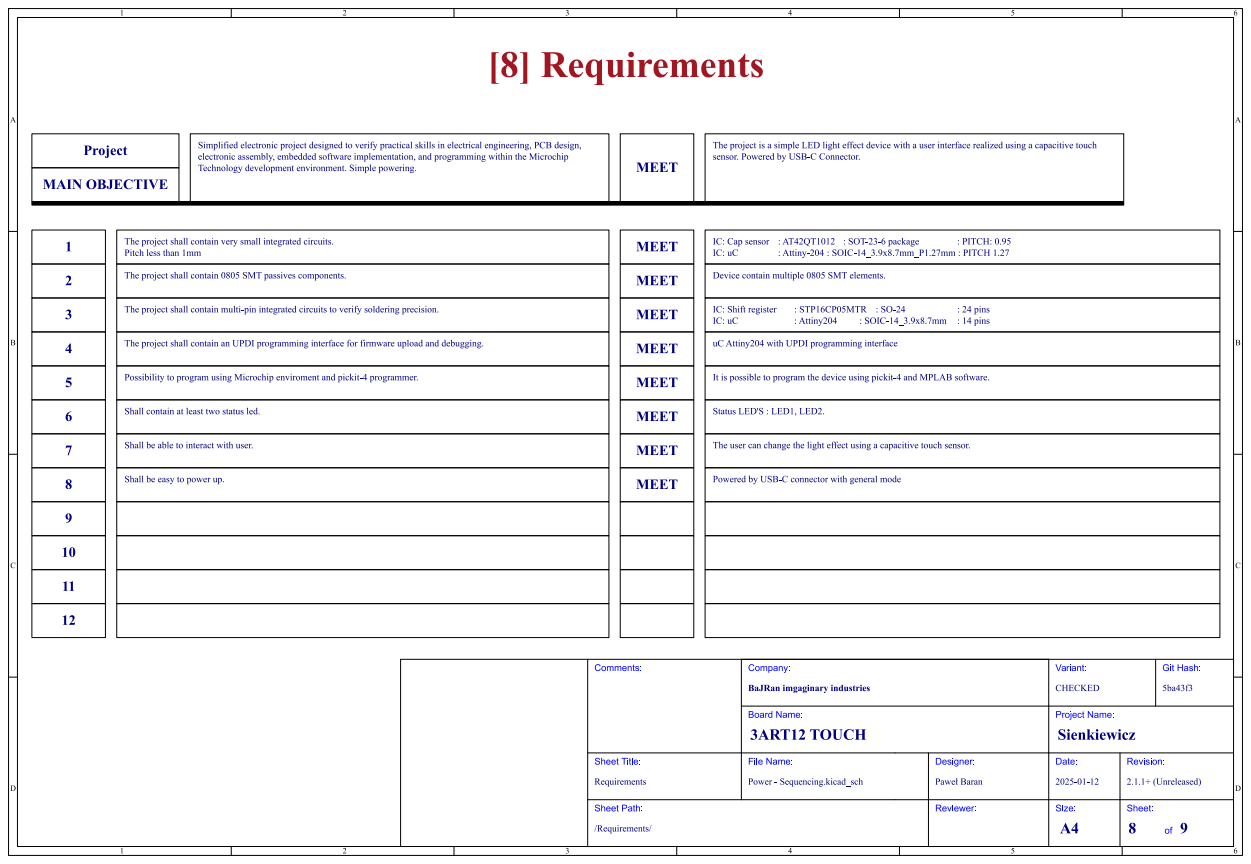
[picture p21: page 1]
Sheet: of 9; Size: A4; Revision: 2.1.1+(Unreleased) Date: Project Name: 2025-01-12 Reviewer: Designer: Power- Sequencing.kicad_sch; þÿPaweB Baran Board Name:; Variant: CHECKED; Company: BaJRanimgaginaryindustries 3ART12TOUCH; Sienkiewicz; Sheet Title:; File Name:; /Requirements/ Sheet Path: Requirements Comments:; Git Hash: 5ba43f3 9; Technologydevelopmentenvironment.Simplepowering.; MEET; Theprojectis a simpleLED light effectdevicewith a userinterfacerealizedusinga capacitivetouch Project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

Simplified electronicprojectdesignedto verify practicalskills in electricalengineering,PCBdesign, electronicassembly,embeddedsoftwareimplementation,andprogrammingwithin theMicrochip

Shallbeableto interactwith user. Shallbeeasyto powerup. Shallcontainat leasttwo statusled. Possibilityto programusingMicrochip enviromentandpickit-4 programmer. Theprojectshallcontainmulti-pin integratedcircuitsto verify solderingprecision. Theprojectshallcontainvery smallintegratedcircuits. Pitchlessthan1mm

Theprojectshallcontain0805SMT passivescomponents. TheprojectshallcontainanUPDI programminginterfacefor firmwareuploadanddebugging.

It is possibleto programthedeviceusingpickit-4 andMPLAB software. Poweredby USB-Cconnectorwith generalmode Theusercanchangethelight effectusinga capacitivetouchsensor. MEET

uC Attiny204 with UPDI programminginterface StatusLED'S: LED1, LED2.

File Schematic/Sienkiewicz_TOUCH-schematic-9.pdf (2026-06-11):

# [9] RevisionHistory

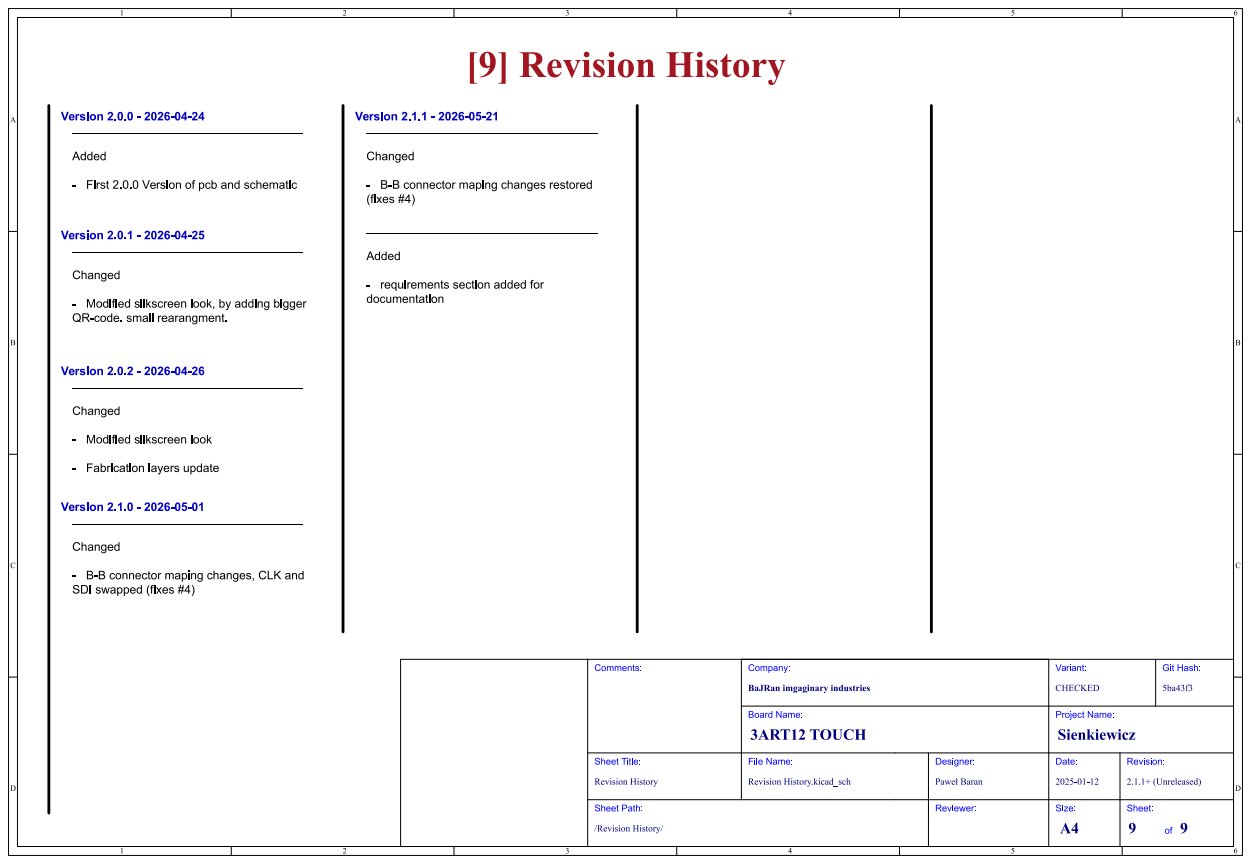
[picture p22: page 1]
Sheet: of 9; Size: A4; Revision: 2.1.1+(Unreleased) Date: Project Name: 2025-01-12 Reviewer: Designer: RevisionHistory.kicad_sch; þÿPaweB Baran Board Name:; Variant: CHECKED; Company: BaJRanimgaginaryindustries 3ART12TOUCH; Sienkiewicz; Sheet Title:; File Name:; /RevisionHistory/ Sheet Path: RevisionHistory Comments:; Git Hash: 5ba43f3 Version 2.0.1 - 2026-04-25; ___________________________________ Added; Version 2.0.0 - 2026-04-24; ___________________________________ Changed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

- First 2.0.0 Version of pcb and schematic

- B-B connector maping changes restored
(fixes #4) ___________________________________ Added

- requirements section added for
documentation

- Modified silkscreen look, by adding bigger

- Modified silkscreen look

- Fabrication layers update

- B-B connector maping changes, CLK and
SDI swapped (fixes #4)

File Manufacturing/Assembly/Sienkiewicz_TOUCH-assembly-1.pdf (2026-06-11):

# 3ART12 TOUCH Assembly Document

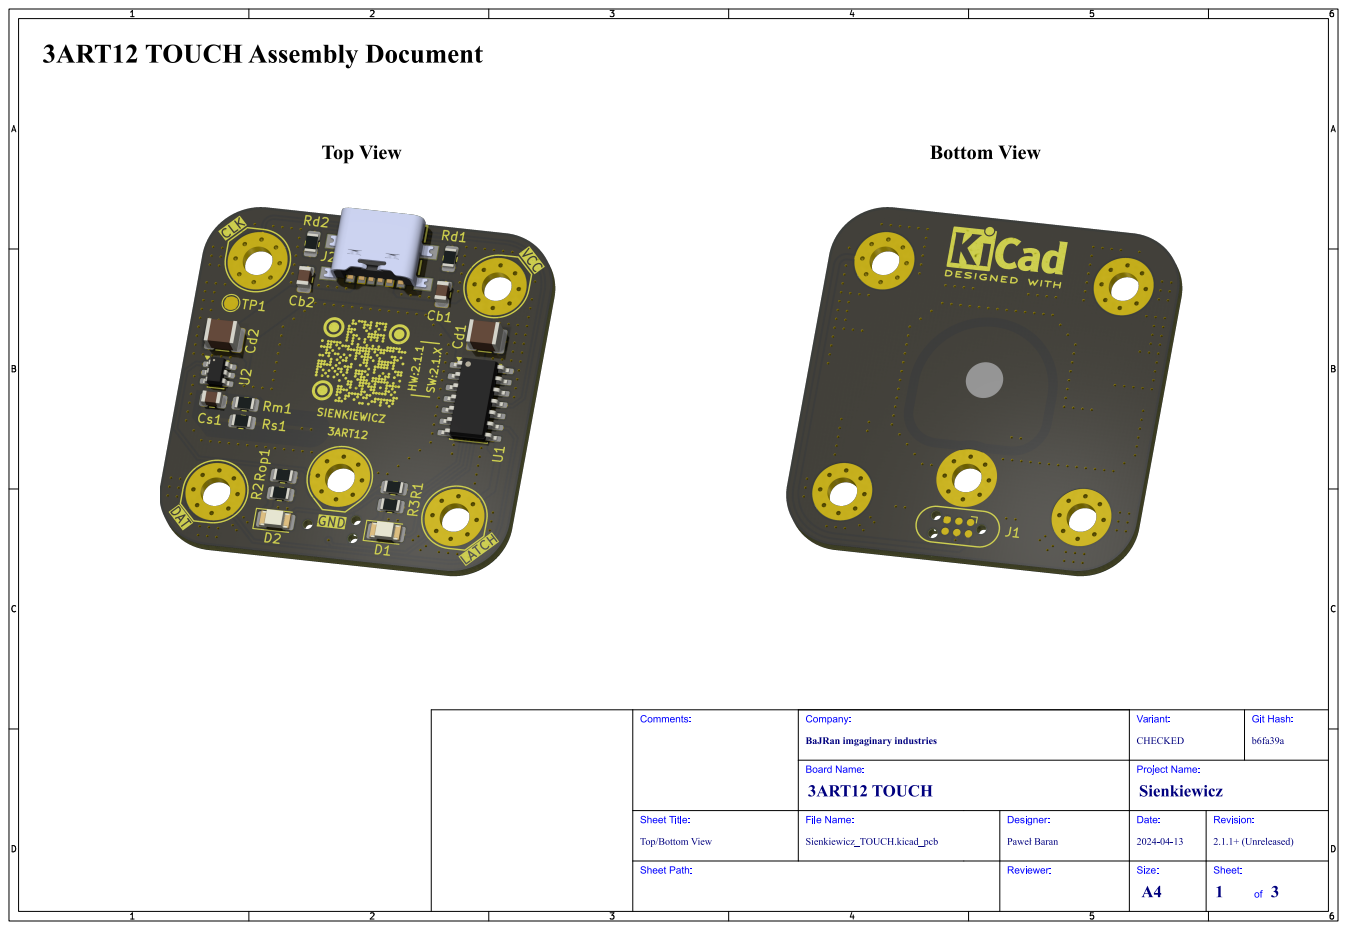
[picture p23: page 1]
Git; Hash:; Comments:; Sheet Path:; Sheet Title:; File Name:; 3ART12 TOUCH; Sienkiewicz; Company:; CHECKED; Variant:; Board Name:; Sienkiewicz_TOUCH.kicad_pcb; Paweł Baran; Designer:; Reviewer:; Project Name:; Date:; 2.1.1+ (Unreleased); Revision:; Size:; Sheet: 1

BaJRan imgaginary industries

Top/Bottom View

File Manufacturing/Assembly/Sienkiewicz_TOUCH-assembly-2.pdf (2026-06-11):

# Top Assembly (Scale 1:1)

# 3ART12 TOUCH Assembly Document

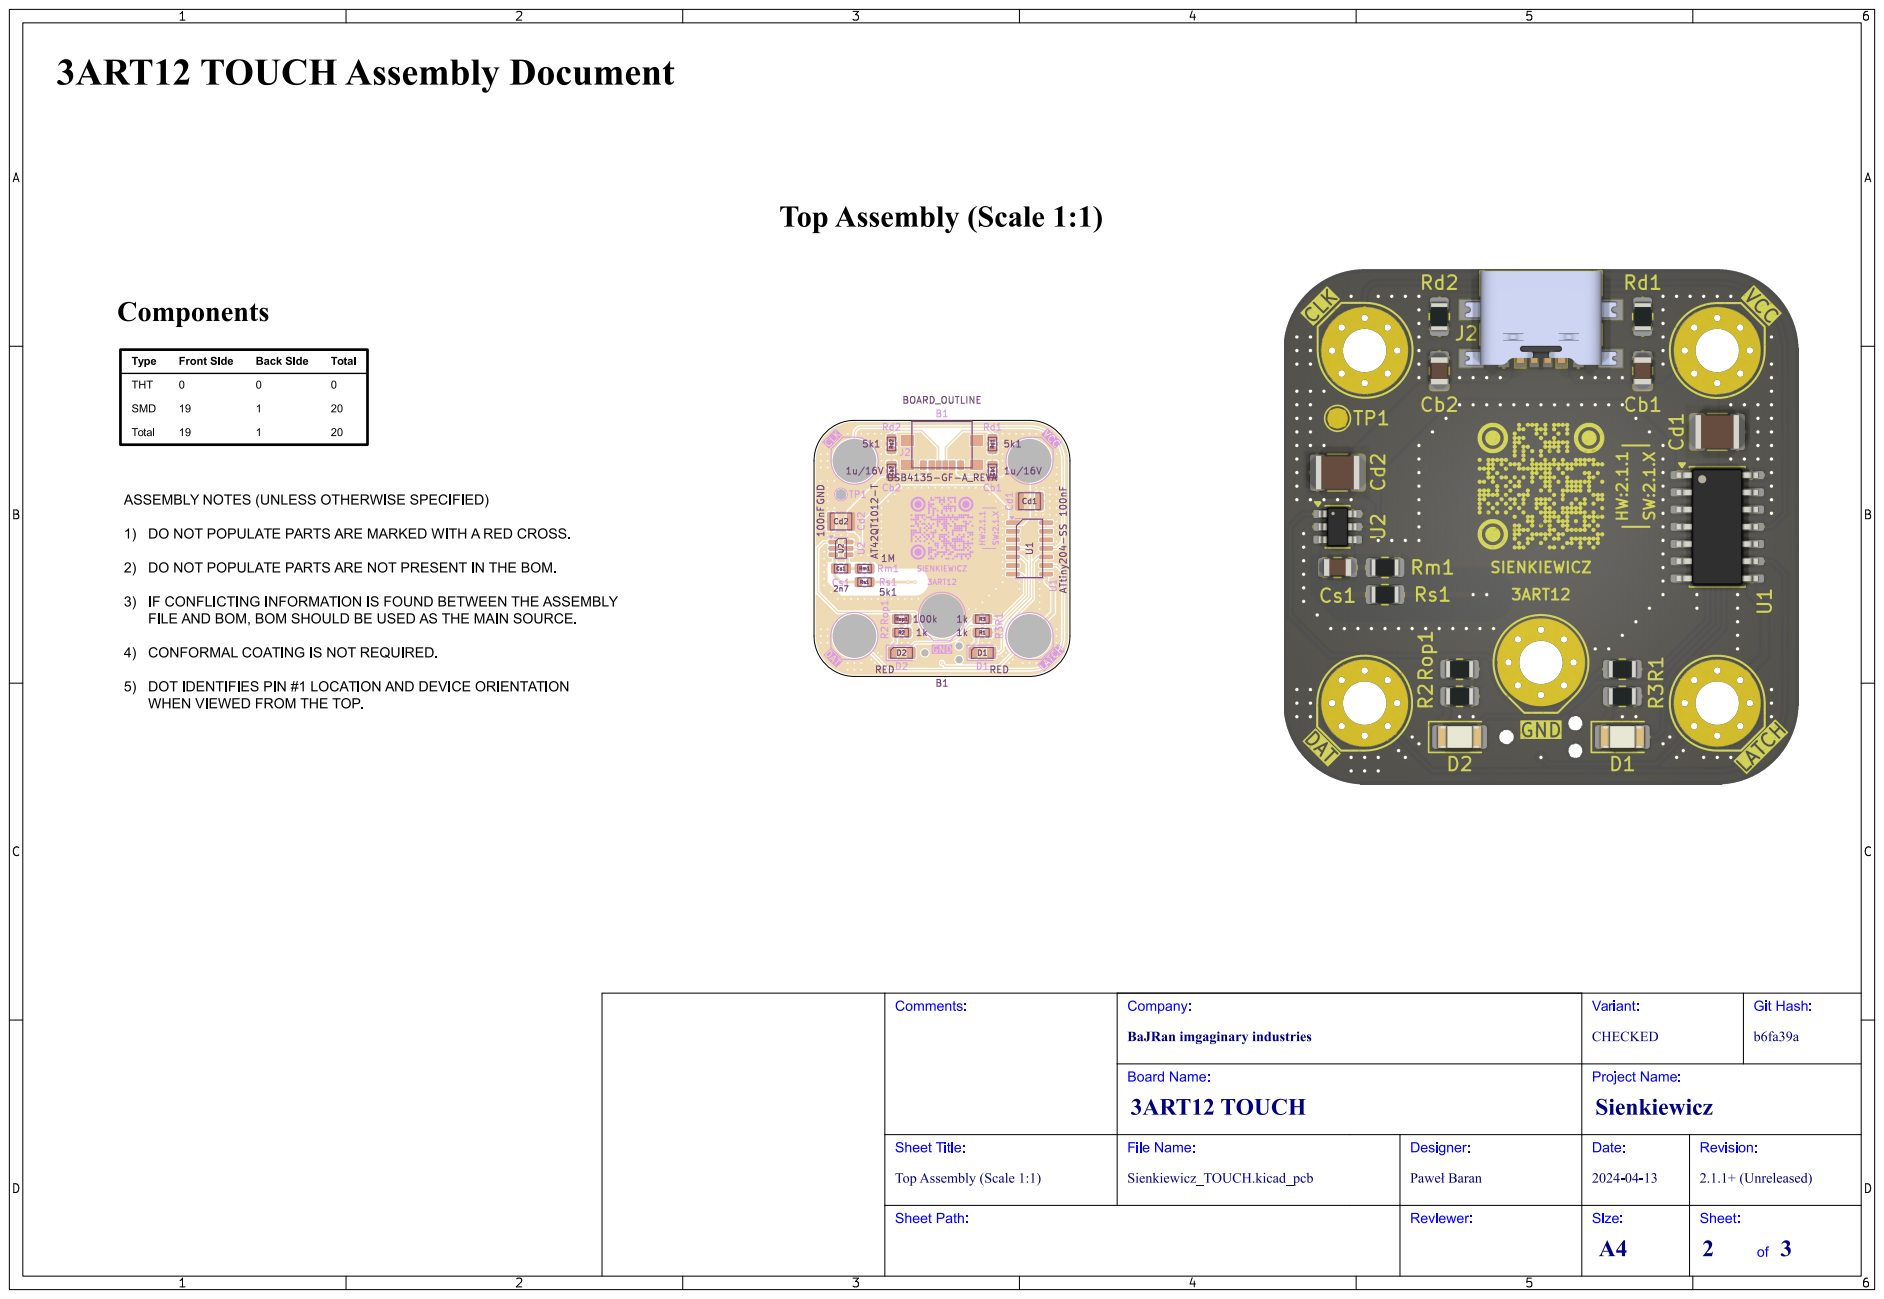
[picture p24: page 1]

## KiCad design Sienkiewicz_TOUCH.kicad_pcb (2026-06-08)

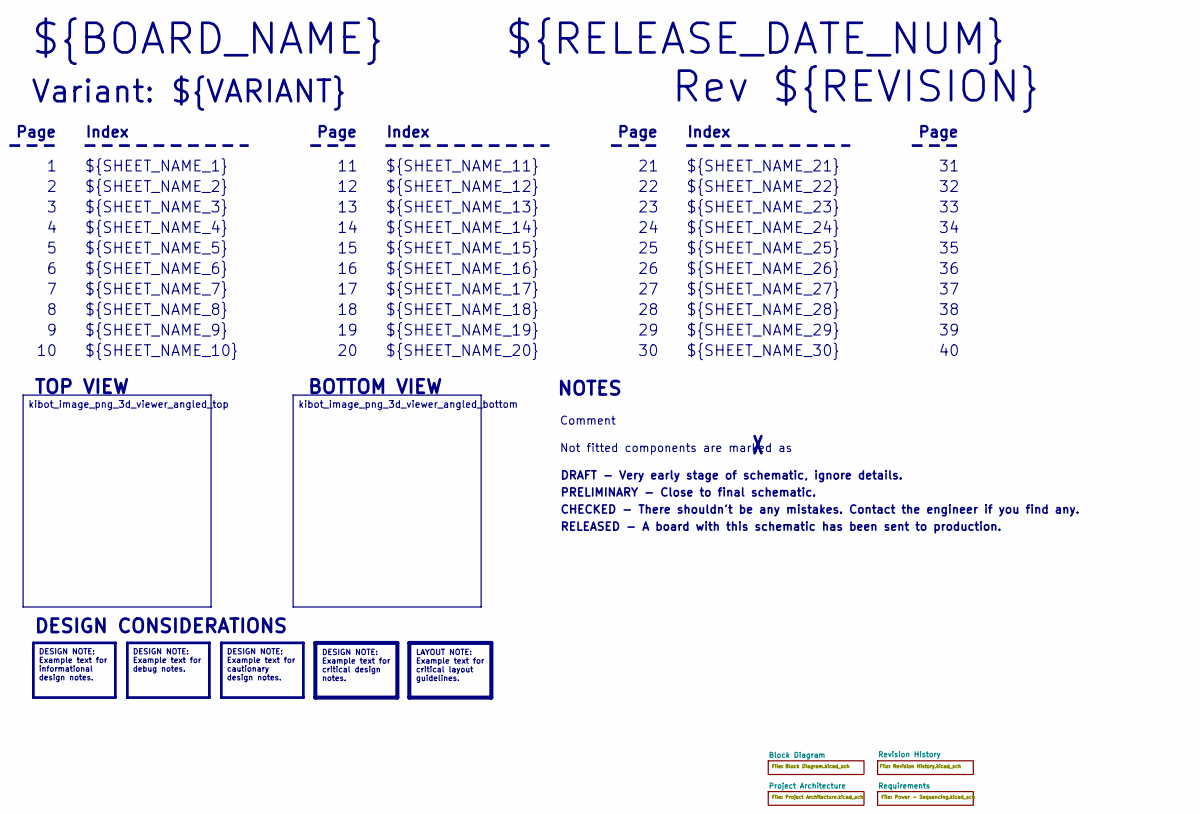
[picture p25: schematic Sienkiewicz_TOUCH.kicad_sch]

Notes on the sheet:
Variant: ${VARIANT}
RELEASED - A board with this schematic has been sent to production.
${SHEET_NAME_24}
Index
Page
PRELIMINARY - Close to final schematic.
${SHEET_NAME_22}
DRAFT - Very early stage of schematic, ignore details.
${SHEET_NAME_12}
${SHEET_NAME_8}
${SHEET_NAME_2}
${SHEET_NAME_5}
${SHEET_NAME_20}
${SHEET_NAME_23}
${RELEASE_DATE_NUM}
Not fitted components are marked as
${SHEET_NAME_11}
${SHEET_NAME_6}
${SHEET_NAME_26}
Rev ${REVISION}
${SHEET_NAME_15}
CHECKED - There shouldn't be any mistakes. Contact the engineer if you find any.
BOTTOM VIEW
${SHEET_NAME_14}
${SHEET_NAME_21}
${SHEET_NAME_17}
${SHEET_NAME_18}
${SHEET_NAME_7}
${BOARD_NAME}
NOTES
${SHEET_NAME_1}
${SHEET_NAME_9}
${SHEET_NAME_29}
${SHEET_NAME_16}
${SHEET_NAME_3}
${SHEET_NAME_19}
Comment
TOP VIEW
${SHEET_NAME_10}
${SHEET_NAME_28}

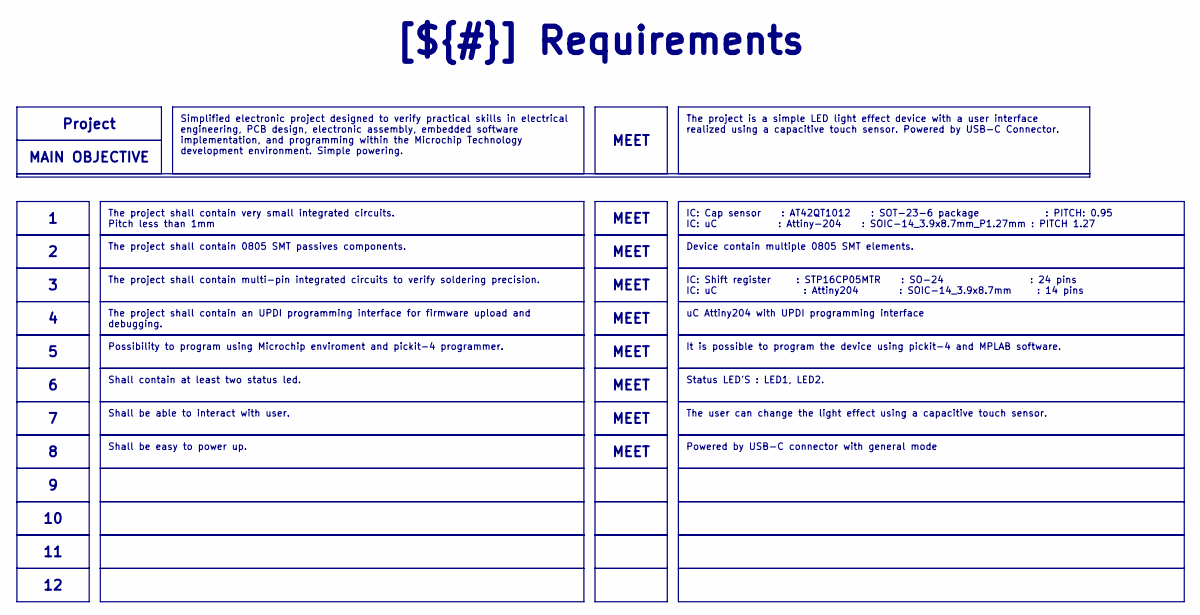
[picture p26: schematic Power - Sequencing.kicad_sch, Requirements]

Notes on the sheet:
Powered by USB-C connector with general mode
IC: Cap sensor : AT42QT1012 : SOT-23-6 package : PITCH: 0.95 IC: uC : Attiny-204 : SOIC-14_3.9x8.7mm_P1.27mm : PITCH 1.27
Simplified electronic project designed to verify practical skills in electrical engineering, PCB design, electronic assembly, embedded software implementation, and programming within the Microchip Technology development environment. Simple powering.
Shall contain at least two status led.
The project shall contain very small integrated circuits. Pitch less than 1mm
uC Attiny204 with UPDI programming interface
Status LED'S : LED1, LED2.
MEET
Shall be easy to power up.
Project
The project shall contain an UPDI programming interface for firmware upload and debugging.
[${#}] ${TITLE}
IC: Shift register : STP16CP05MTR : SO-24 : 24 pins IC: uC : Attiny204 : SOIC-14_3.9x8.7mm : 14 pins
It is possible to program the device using pickit-4 and MPLAB software.
MAIN OBJECTIVE
The user can change the light effect using a capacitive touch sensor.
The project shall contain multi-pin integrated circuits to verify soldering precision.
The project shall contain 0805 SMT passives components.
Device contain multiple 0805 SMT elements.
Possibility to program using Microchip enviroment and pickit-4 programmer.
Shall be able to interact with user.
The project is a simple LED light effect device with a user interface realized using a capacitive touch sensor. Powered by USB-C Connector.

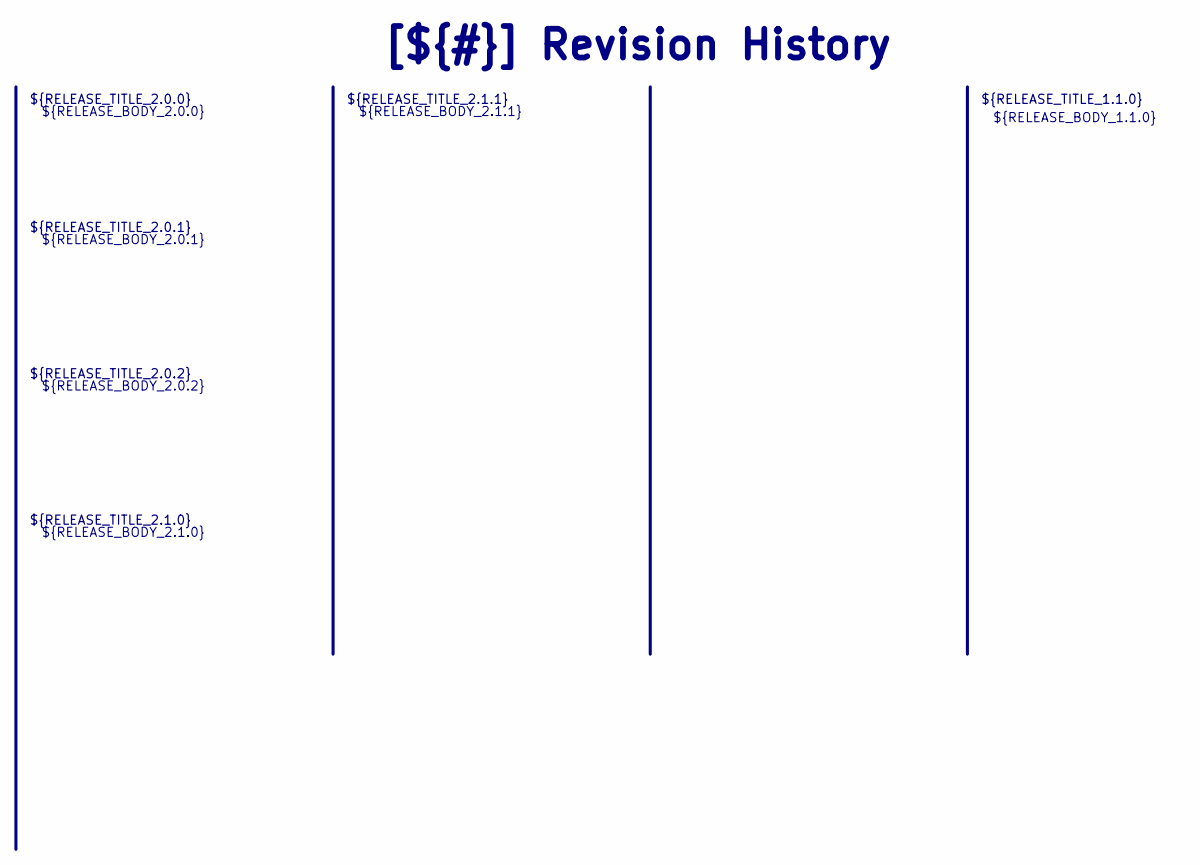
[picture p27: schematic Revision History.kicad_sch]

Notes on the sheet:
${RELEASE_BODY_1.1.0}
${RELEASE_BODY_2.1.1}
[${#}] ${TITLE}
${RELEASE_BODY_2.0.0}
${RELEASE_TITLE_2.1.1}
${RELEASE_BODY_2.1.0}
${RELEASE_TITLE_2.0.2}
${RELEASE_TITLE_2.1.0}
${RELEASE_BODY_2.0.2}
${RELEASE_BODY_2.0.1}
${RELEASE_TITLE_2.0.0}
${RELEASE_TITLE_2.0.1}
${RELEASE_TITLE_1.1.0}

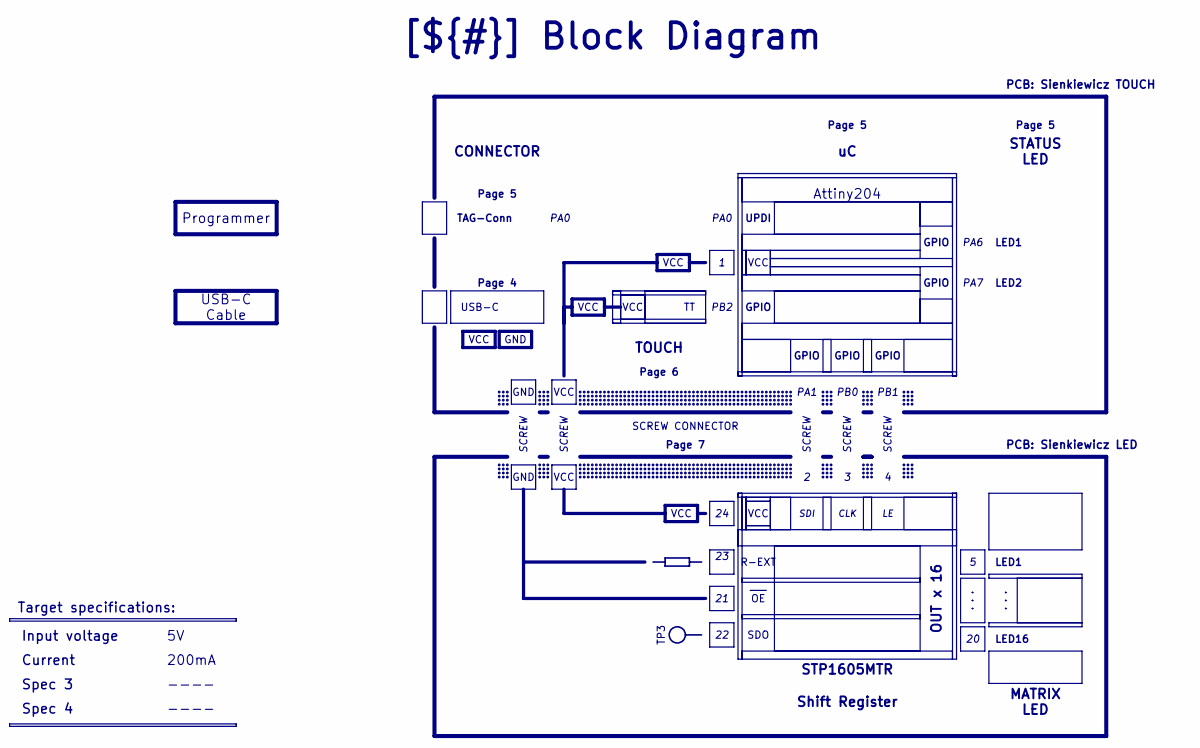
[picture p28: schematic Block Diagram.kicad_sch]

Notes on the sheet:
PCB: Sienkiewicz LED
PCB: Sienkiewicz TOUCH
TP3
PB1
Page 5
STATUS LED
GND
. . .
Spec 4
LED2
VCC
USB-C Cable
----
STP1605MTR
SCREW
GPIO
LED1
R-EXT
TAG-Conn
PA7
Shift Register
CLK
[${#}] ${TITLE}
200mA
Input voltage
TOUCH
Page 6
CONNECTOR
SCREW CONNECTOR
Target specifications:
Programmer
Attiny204
Page 4
PA1
Spec 3
MATRIX LED
Current
Page 7
PB0
PA0

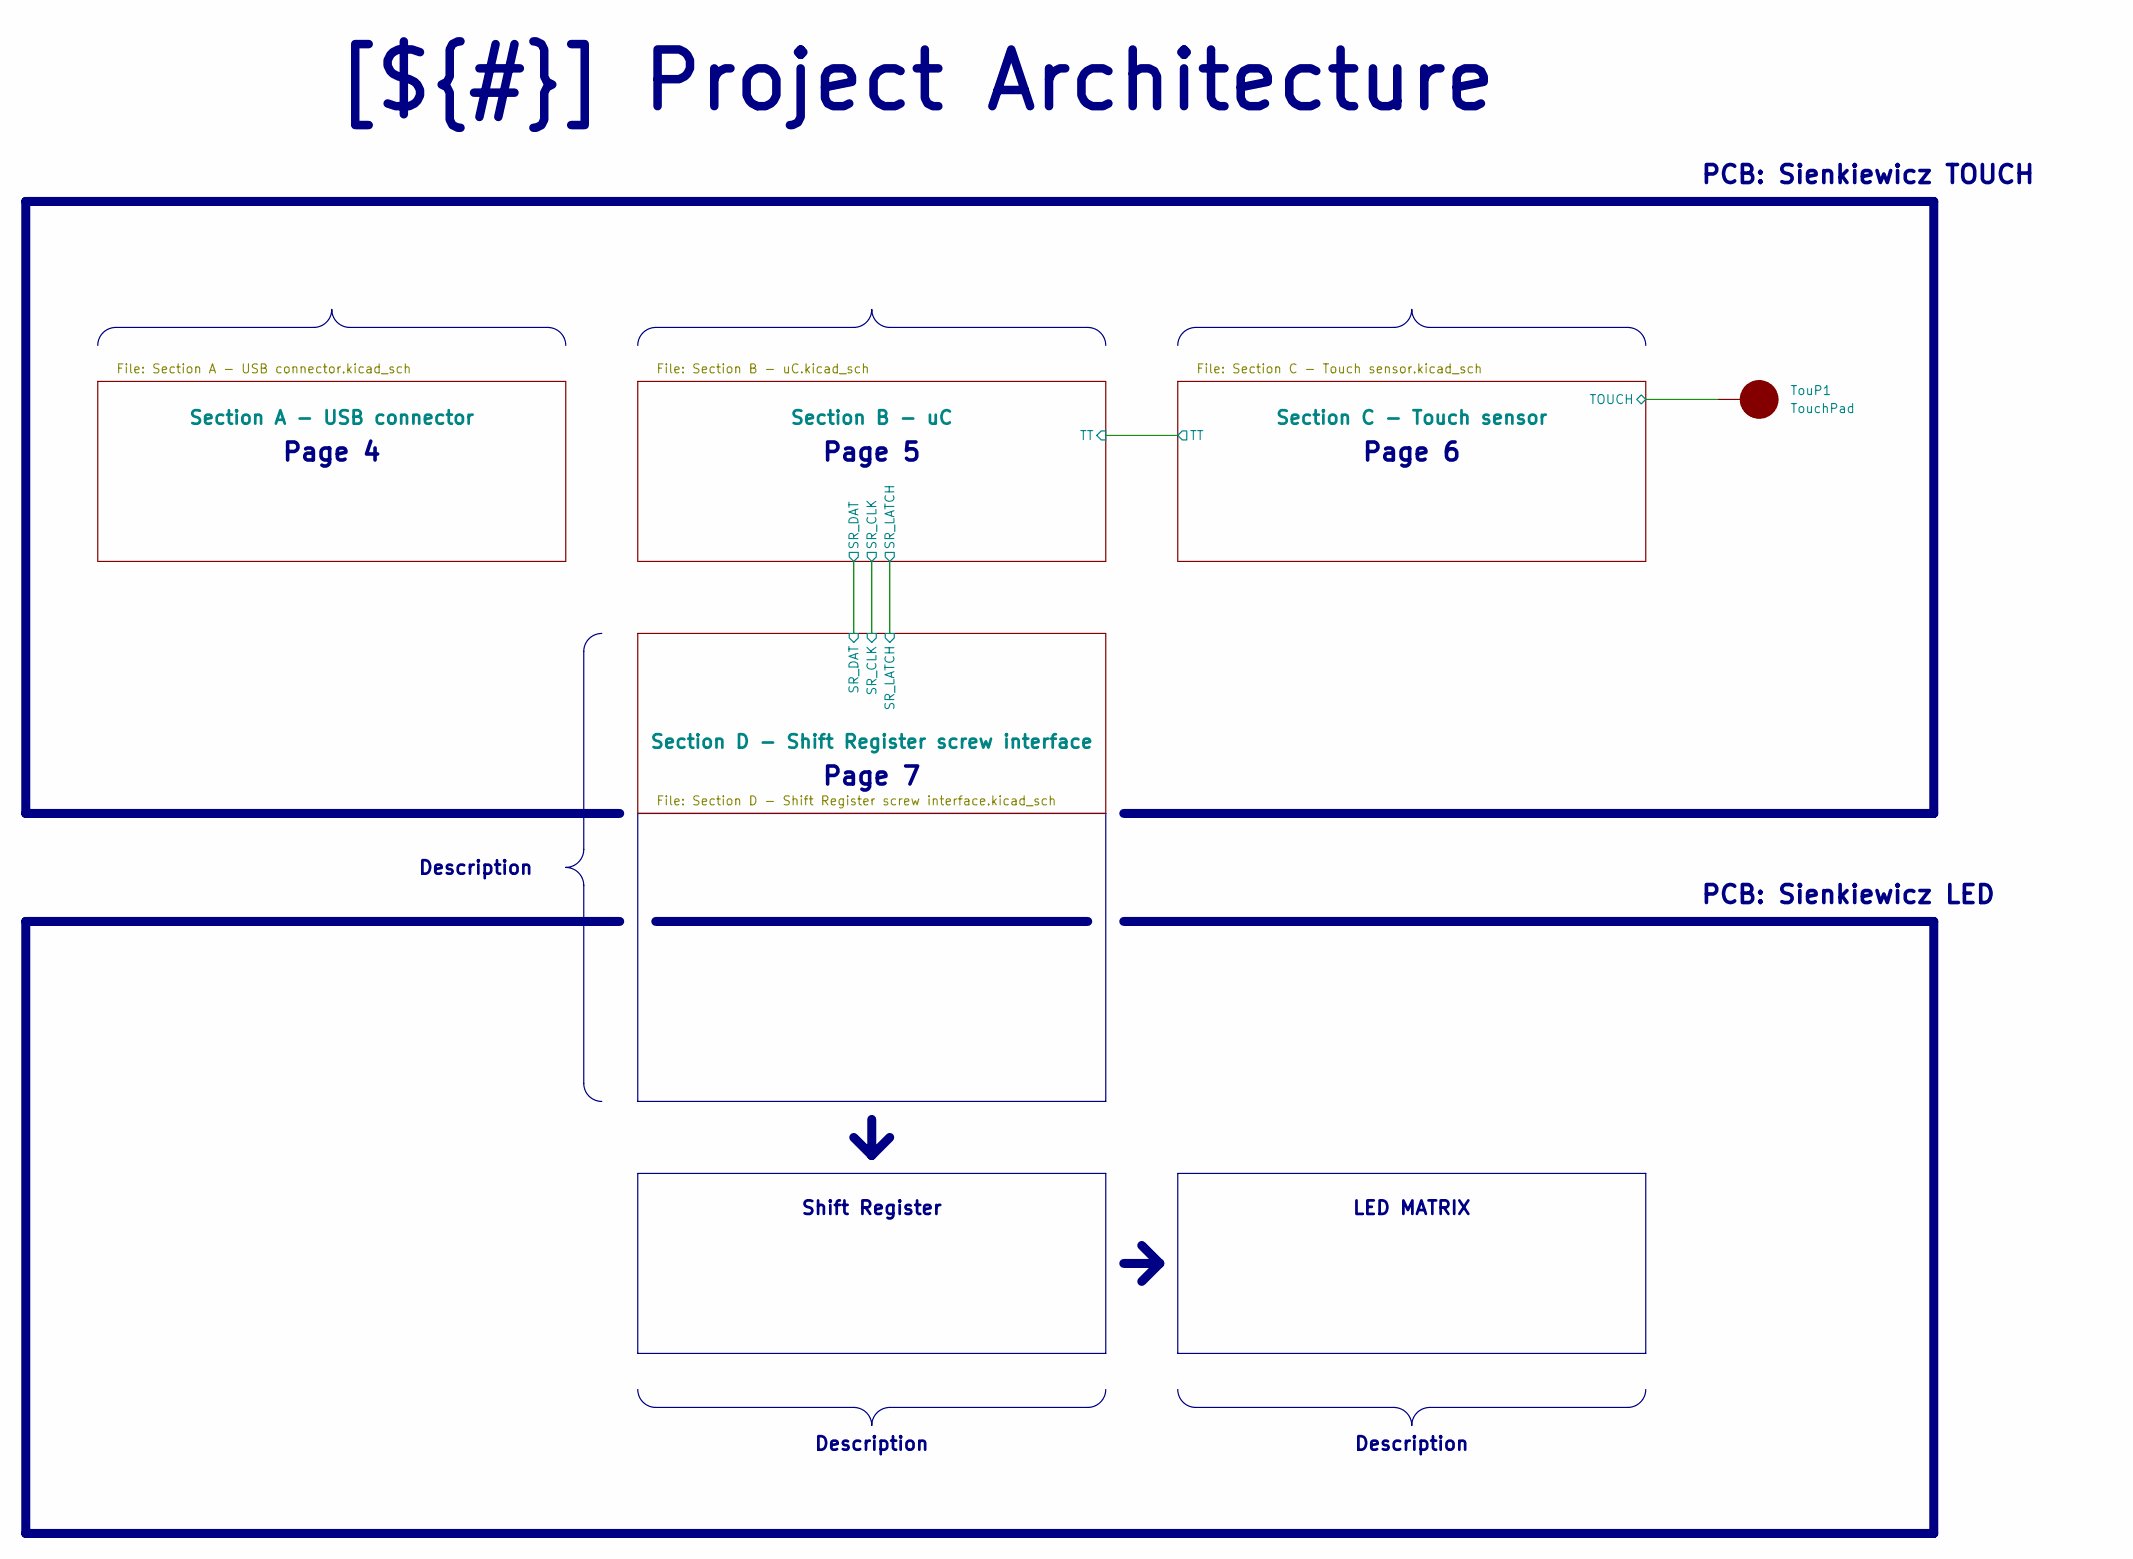
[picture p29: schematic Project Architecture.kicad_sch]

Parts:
TouP1: TouchPad; TouchPAD

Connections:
/Project Architecture/Section C - Touch sensor/TOUCH: TouP1.1 (TOUCH); also elsewhere on the board

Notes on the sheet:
LED MATRIX
Page 6
Shift Register
Page 7
Page 5
PCB: Sienkiewicz LED
PCB: Sienkiewicz TOUCH
Page 4
Description
[${#}] ${TITLE}

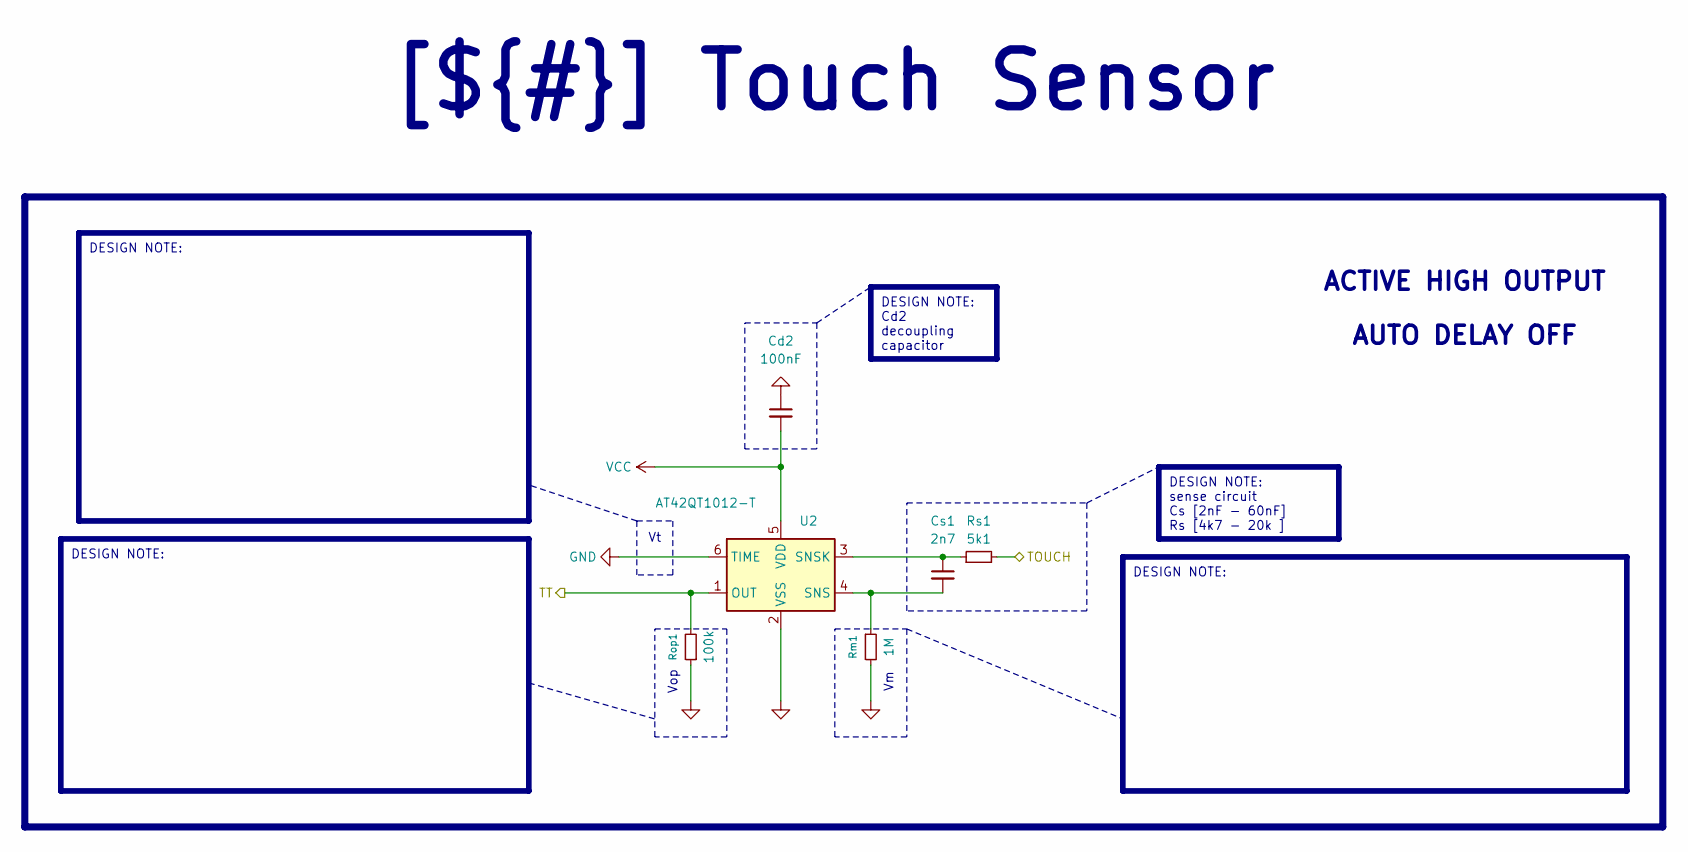
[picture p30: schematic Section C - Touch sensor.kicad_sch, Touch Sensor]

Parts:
Cd2: 100nF; C_1210_3225Metric
Cs1: 2n7; C_0805_2012Metric
Rm1: 1M; R_0805_2012Metric
Rop1: 100k; R_0805_2012Metric
Rs1: 5k1; R_0805_2012Metric
U2: AT42QT1012-T; SOT-23-6

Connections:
/Project Architecture/Section B - uC/TT: Rop1.2, U2.1 (OUT); also elsewhere on the board
/Project Architecture/Section C - Touch sensor/TOUCH: Rs1.2; also elsewhere on the board
GND: Cd2.1, Rm1.2, Rop1.1, U2.2 (VSS), U2.6 (TIME); also elsewhere on the board
unnamed: Cs1.2, Rm1.1, U2.4 (SNS)
unnamed: Cs1.1, Rs1.1, U2.3 (SNSK)
VCC: Cd2.2, U2.5 (VDD); also elsewhere on the board

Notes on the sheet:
Vop
DESIGN NOTE:
DESIGN NOTE: Cd2 decoupling capacitor
[${#}] ${TITLE}
DESIGN NOTE:
AUTO DELAY OFF
DESIGN NOTE: sense circuit Cs [2nF - 60nF] Rs [4k7 - 20k ]
ACTIVE HIGH OUTPUT

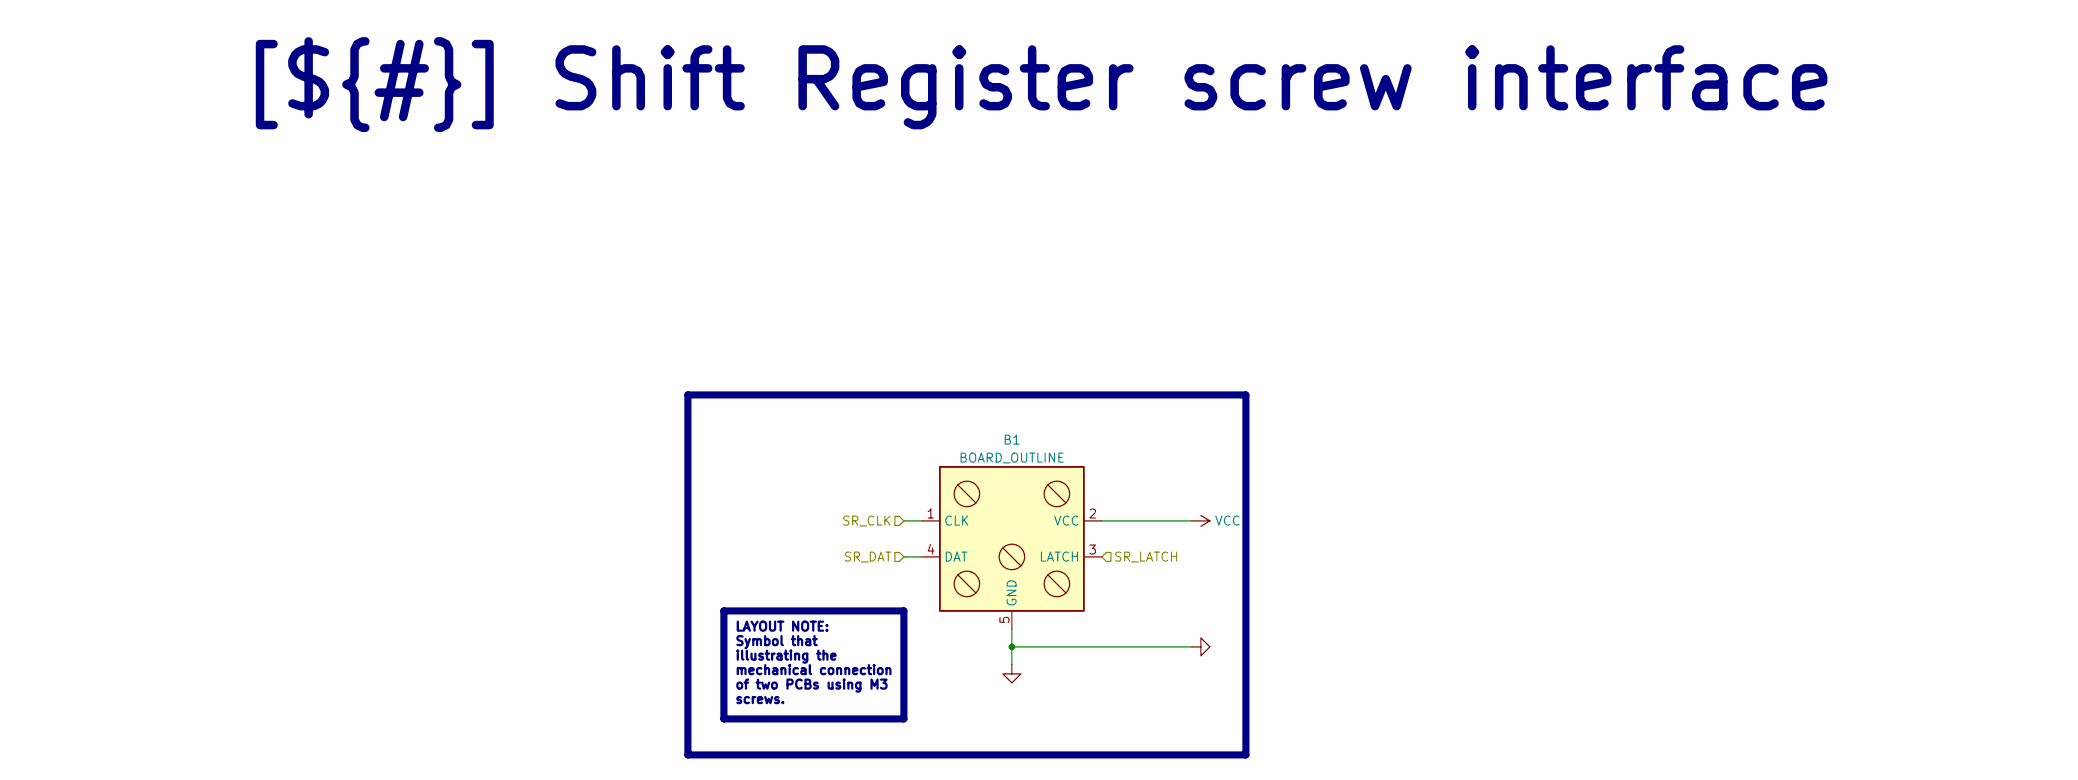
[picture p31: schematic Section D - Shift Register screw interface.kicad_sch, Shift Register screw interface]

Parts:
B1: BOARD_OUTLINE; Sienkiewicz

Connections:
/Project Architecture/Section B - uC/SR_CLK: B1.1 (CLK); also elsewhere on the board
/Project Architecture/Section B - uC/SR_DAT: B1.4 (DAT); also elsewhere on the board
/Project Architecture/Section B - uC/SR_LATCH: B1.3 (LATCH); also elsewhere on the board
GND: B1.5 (GND); also elsewhere on the board
VCC: B1.2 (VCC); also elsewhere on the board

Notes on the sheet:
LAYOUT NOTE: Symbol that illustrating the mechanical connection of two PCBs using M3 screws.
[${#}] ${TITLE}

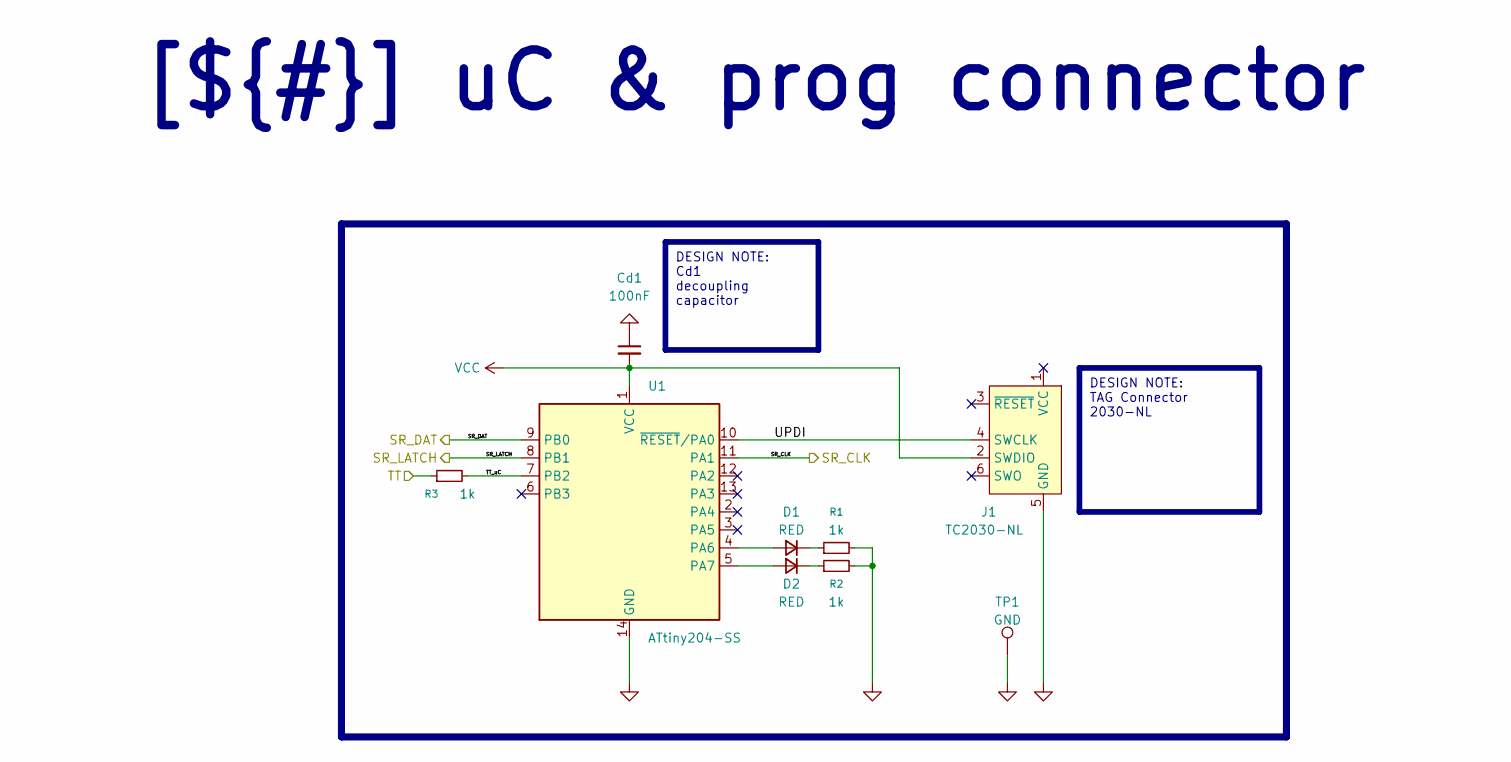
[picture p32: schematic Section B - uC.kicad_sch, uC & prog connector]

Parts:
Cd1: 100nF; C_1210_3225Metric
D1, D2: RED; LED_1206_3216Metric
J1: TC2030-NL; Tag-Connect_TC2030-IDC-NL_2x03_P1.27mm_Vertical
R1, R2, R3: 1k; R_0805_2012Metric
TP1: GND; TestPoint_Pad_D1.5mm
U1: ATtiny204-SS; SOIC-14_3.9x8.7mm_P1.27mm

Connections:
/Project Architecture/Section B - uC/SR_CLK: U1.11 (PA1); also elsewhere on the board
/Project Architecture/Section B - uC/SR_DAT: U1.9 (PB0); also elsewhere on the board
/Project Architecture/Section B - uC/SR_LATCH: U1.8 (PB1); also elsewhere on the board
/Project Architecture/Section B - uC/TT: R3.1; also elsewhere on the board
/Project Architecture/Section B - uC/TT_uC: R3.2, U1.7 (PB2)
/Project Architecture/Section B - uC/UPDI: J1.4 (SWCLK), U1.10 (~RESET/PA0)
GND: Cd1.1, J1.5 (GND), R1.2, R2.2, TP1.1, U1.14 (GND); also elsewhere on the board
unnamed: D1.2 (A), U1.4 (PA6)
unnamed: D1.1 (K), R1.1
unnamed: D2.2 (A), U1.5 (PA7)
unnamed: D2.1 (K), R2.1
VCC: Cd1.2, J1.2 (SWDIO), U1.1 (VCC); also elsewhere on the board

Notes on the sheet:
[${#}] ${TITLE}
DESIGN NOTE: Cd1 decoupling capacitor
DESIGN NOTE: TAG Connector 2030-NL

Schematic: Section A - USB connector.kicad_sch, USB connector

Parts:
Cb1, Cb2: 1u/16V; C_0805_2012Metric
J2: USB4135-GF-A_REVA; GCT_USB4135-GF-A_REVA; PARTREV A; DigiKey_Part_Number 2073-USB4135-GF-ATR-ND
Rd1, Rd2: 5k1; R_0805_2012Metric

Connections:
GND: Cb1.1, Cb2.1, J2.A12 (GND_A), J2.B12 (GND_B), Rd1.2, Rd2.2; also elsewhere on the board
unnamed: J2.A5 (CC), Rd1.1
unnamed: J2.B5 (VCONN), Rd2.1
VCC: Cb1.2, Cb2.2, J2.A9 (VBUS_A), J2.B9 (VBUS_B); also elsewhere on the board

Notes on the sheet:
www.usb.org/sites/default/files/USB%20Type-C%20Spec%20R2.0%20-%20August%202019.pdf
J. Pieper ADC investigation
STM32G474 Datasheet p.81
AN5346
DESIGN NOTE: Cb1, Cb2 bulk capacitor
[${#}] ${TITLE}
DESIGN NOTE: Per USB-IF specification, a sink role is established by placing 5.1 kΩ pull-down (Rd) resistors on CC1 and CC2.

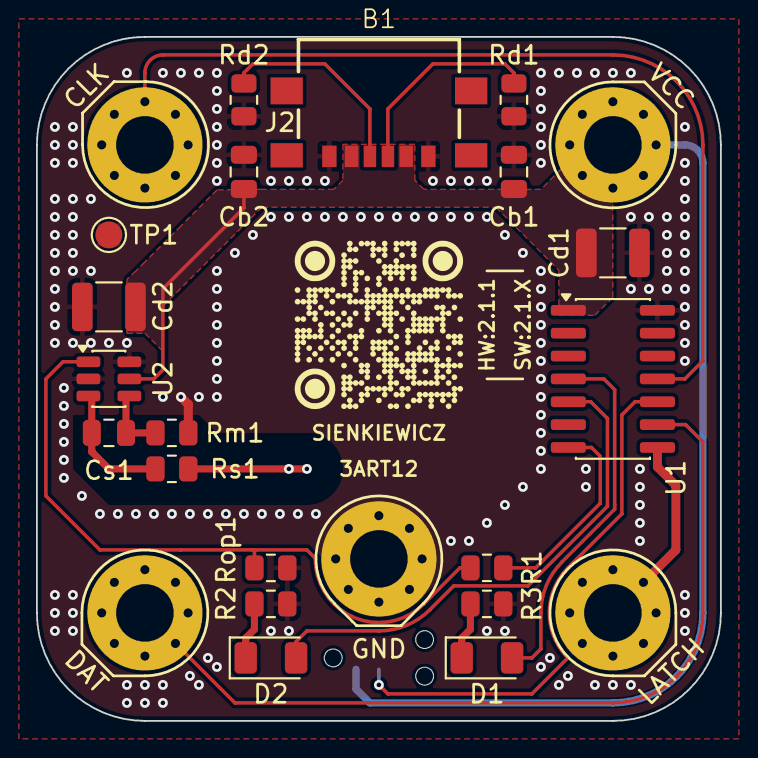
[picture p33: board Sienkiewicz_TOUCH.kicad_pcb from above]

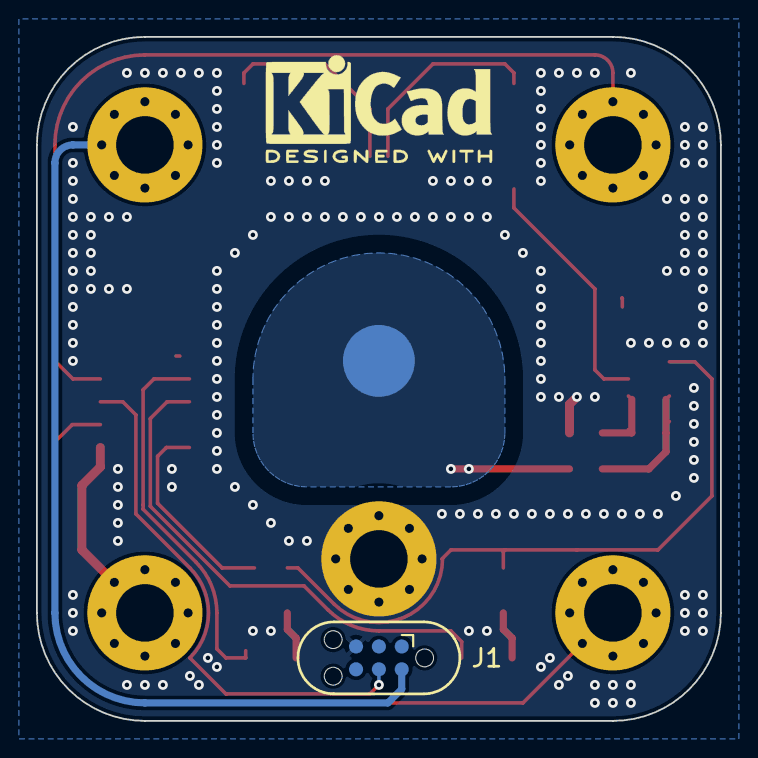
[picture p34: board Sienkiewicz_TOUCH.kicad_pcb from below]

Board: 2 copper layers, 38.0 x 38.0 mm, 22 parts (2 on the bottom side), 17 nets.

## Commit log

2026-04-13 schematic file names changed
    [Project Architecture.kicad_sch, Section A - USB connector.kicad_sch, Section B - uC.kicad_sch]
2026-04-13 Update Outputs
    [Sienkiewicz_TOUCH-bom.csv]
2026-04-13 sienkiewicz library missing value update
    [Section B - uC.kicad_sch, Sienkiewicz_TOUCH.kicad_pcb]
2026-04-14 board updatea
    [Project Architecture.kicad_sch, Section A - USB connector.kicad_sch, Section B - uC.kicad_sch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]
2026-04-14 pcb update
    [Section A - USB connector.kicad_sch, Sienkiewicz_TOUCH.kicad_pcb]
2026-04-15 led1,led2 better documented
    [Section B - uC.kicad_sch, Sienkiewicz_TOUCH.kicad_pcb]
2026-04-15 kicad_prl update
2026-04-15 .kicad_pro resolve problems
2026-04-15 touch pad library creation
    [Project Architecture.kicad_sch, Section A - USB connector.kicad_sch, Section B - uC.kicad_sch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]
2026-04-16 minor updates of shematic and pcb and touch pad library
    [Block Diagram.kicad_sch, Project Architecture.kicad_sch, Section A - USB connector.kicad_sch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]
2026-04-16 [sch] update touch sensor section
    [Section A - USB connector.kicad_sch, Section B - uC.kicad_sch, Section C - Touch sensor.kicad_sch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]
2026-04-17 screw interface update - changed pinout
    [Project Architecture.kicad_sch, Section A - USB connector.kicad_sch, Section B - uC.kicad_sch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]
2026-04-18 [CFG] Configuration update, added bom information fields
    [Project Architecture.kicad_sch, Section A - USB connector.kicad_sch, Section B - uC.kicad_sch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]
2026-04-18 bom update, qr-code added
    [Project Architecture.kicad_sch, Section A - USB connector.kicad_sch, Section B - uC.kicad_sch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]
2026-04-20 [sch] added R3 to prevent high current drain from cap touch chip
    [Section B - uC.kicad_sch, Section C - Touch sensor.kicad_sch, Sienkiewicz_TOUCH.kicad_pcb]
2026-04-24 [pcb] board outline/connection changed / back compatibility not possible
    [Section B - uC.kicad_sch, Section D - Shift Register screw interface.kicad_sch, Sienkiewicz_TOUCH.kicad_pcb]
2026-04-24 project structure cleaning from old files
    [Sienkiewicz_TOUCH-(L1-L6)_NPTH_drill_table.csv, Sienkiewicz_TOUCH-(L1-L6)_drill_table.csv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]
2026-04-24 file refresh
    [Sienkiewicz_TOUCH.kicad_pcb]
2026-04-24 [pcb] checked
    [Revision History.kicad_sch]
2026-04-24 VCC and GND chierarchical labels added
    [Project Architecture.kicad_sch]
2026-04-24 moved the label to force push from local repo
    [Section D - Shift Register screw interface.kicad_sch]
2026-04-24 Update Outputs (release)
    [Sienkiewicz_TOUCH-B_Mask.gbr, Sienkiewicz_TOUCH-B_Paste.gbr, Sienkiewicz_TOUCH-B_Silkscreen.gbr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]
2026-04-24 descriptions on the board update
    [Sienkiewicz_TOUCH.kicad_pcb]
2026-04-25 prepared for 2.0.1 release
    [Revision History.kicad_sch]
2026-04-25 silkscreen, centered LATCH outlie on screw connector
    [Sienkiewicz_TOUCH.kicad_pcb]
2026-04-25 [pcb] silkscreen, version bump to 2.0.1
    [Sienkiewicz_TOUCH.kicad_pcb]
2026-04-25 [pcb] fabrication layers update
    [Sienkiewicz_TOUCH.kicad_pcb]
2026-04-25 prep for 2.0.2 release
    [Revision History.kicad_sch, Sienkiewicz_TOUCH.kicad_pcb]
2026-04-27 changed signal layer names for JLCPCB naming convention
    [Sienkiewicz_TOUCH.kicad_pcb]
2026-04-30 initial prep for SR signals reassignment (refs #4)
    [Sienkiewicz_TOUCH.kicad_pcb]
2026-04-30 reassign SR signals for clean design (fixes #4)
    [Section B - uC.kicad_sch, Section D - Shift Register screw interface.kicad_sch, Sienkiewicz_TOUCH.kicad_pcb]
2026-04-30 revision history update, prep for V2.1.0 relese
    [Revision History.kicad_sch]
2026-04-30 revisiion history.kicad_sch update
    [Revision History.kicad_sch]
2026-05-21 documentation update / block diagram
    [Block Diagram.kicad_sch, Power - Sequencing.kicad_sch, Project Architecture.kicad_sch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]
2026-05-21 removed hierarhical vcc labels
    [Section A - USB connector.kicad_sch, Section B - uC.kicad_sch, Section C - Touch sensor.kicad_sch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]
2026-05-21 routing update #4
    [Project Architecture.kicad_sch, Section B - uC.kicad_sch, Section D - Shift Register screw interface.kicad_sch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]
2026-05-21 documentation update /requirements /schematic
    [Power - Sequencing.kicad_sch, Revision History.kicad_sch, Sienkiewicz_TOUCH.kicad_pcb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]
2026-05-21 prep for 2.1.1 release
    [Revision History.kicad_sch]
2026-05-21 2.1.1 fixes #4
    [Power - Sequencing.kicad_sch]
2026-06-08 readme.md update
    [KDT_Hierarchical_KiBot.step, Sienkiewicz_TOUCH.kicad_pcb]
2026-06-11 schematic update
    [Block Diagram.kicad_sch]
2026-06-11 schematid update - block diagram fix
    [Block Diagram.kicad_sch]
